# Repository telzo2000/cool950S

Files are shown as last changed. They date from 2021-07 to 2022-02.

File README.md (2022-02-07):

# cool950S
# ビルドガイド<br>
https://github.com/telzo2000/cool950S/blob/main/buildguide_for_cool950S.md

# What is cool950S?

cool950S is desined by m.ki.
<br>
cool950S is a split keyboard.
<br>
I didn't have a cool 40% keyboard, so I made one.
<br>

# 開発の経緯(Development history)<br>
cool943Sの製作した後，それに合うようなキーキャップを探したが，中々合致するものがなかった。
特にエンターキーは40%キーボードで構成されている1.75Uにしたため，ベースキット以外に，40%キットを追加購入するなど，お金がかかる事となった。
そのため，ベースキットのみで完成するキーボードがいいと思い，cool950Sの特徴の一つとした。
他に，矢印キーをレイヤーキーとの組み合わせでなく，標準で打鍵できる方が良いのかなとも考えた。
右側手前に矢印キーを置くことも特徴の一つとした。
cool943Sのバックスペースキーは2Uであった。
それを1Uサイズにすることで，スタビライザーが一つ減る。
さらにPキーの隣にひとつキーを加えられると考えた。
それらにより，右側1行目は，7つのキーとなり，左側１行目の６つのキーと合致しない。
ファームウェアの見直しが必要となる。
ROWが7になるのであれば，左側にも1つキーを加えられると考えた。
そこで，一番左側に縦方向に4つキーを加えることとした。
アルティザンキーキャップを置くことも、マクロキーを設定することもできると考えた。
バックスペースキーを1Uとすることで，左右どちらにも１行目端部にpro microの設置が可能となった。
これにより，cool943Sよりも余白の少ないデザインとすることができた。
代わりに，cool943Sよりも背の高いキーボードとなる。<br>
cool943Sはpro microを１行目キーの奥側に設置することで，背の低いキーボードに仕上げた。
私の場合は，パームレストなしで使うことができ，良い高さである。
多少の余白も手に当たることがない。
今回は１行目外端部下に設置した。
pro microを含むことで高さの制約を受けている。
トッププレート上面からボトムプレート下面までの厚みは，cool950Sが14.6mmで，cool943Sが11.6mmである。<br>
<br>
令和３年７月１７日にLEDの装着を行う。
操作の仕方がわからないが、点灯した。
配線のミスはないことが確認できた。
あとはオプション部品となるアクリル部品の設計が残っている。<br>
令和3年7月上旬に、試作1号が完成した。
アクリルのトッププレートとボトムプレートでPCBを挟むサンドイッチマウントである。
仮組みの段階で、スタビ用に開けた穴が小さいこと、その近くにあるネジとの距離が近すぎて、ネジやスペーサーに干渉することがわかった。
それにより、アクリル、PCBの両方を修正して、Ver.1.1を発注した。
ただ、スタビが使えないだけの試作1号であるが、それ以外の問題が無いか確認するため、実際に組んで、ファームウェアを入れてみた。
ファームウェアの修正は必要であったが、配線等のミスはなかった。
半田付けのミスがあり、１枚基板を廃棄した。<br>
その後、ビルド環境のラズベリーパイが不調となり、新しく構築することとなった。
新しい環境でcool950SのREMAP対応のファームウェアを作り、7月10日に完成した。
ついでに、他のキーキャップへの換装をし、ツイートした。<br>
https://twitter.com/0002ozlet/status/1413727164780843009
<br>
令和３年７月18日にオプション部品と考えていた、アクリル部品を発注した。<br>
7月24日にアクリル部品は到着して、装着した。
cool950Sはアクリル積層による密閉型ケースとなった。
当初、アクリルサンドイッチ構造と、オプションによるアクリル積層の密閉型の選択できる形を考えていた。<br>
しかし、できあがりを見て、オプションではなく、標準でアクリル積層の密閉型ケースとすることに決めた。<br>
発注した５セット分の余剰として、４セットを頒布する予定である。
スタビライザーが使えないver.1.0も訳あり品として頒布する予定である。<br>
現在、本サイトを含めて、準備をしている。
<br>
令和３年8月11日追記<br>
8月上旬にアクリル積層による密閉型ケースのcool950Sを頒布した。<br>
後日、スタビライザーが使えないver.1.0も頒布する予定。<br>

<br>
# 今後の予定（Future plans）

☑ver1.1が届いたら、一台分組み立て及び撮影<br>
☑ビルドガイドの作成<br>
☑Boothでの残りの頒布。<br>
□オプション部品の販売。<br>
<br><br>

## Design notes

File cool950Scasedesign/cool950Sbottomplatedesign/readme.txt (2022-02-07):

These are the components of the keyboard case.
The red line is the inner cutline.
The black line is the outer cutline.

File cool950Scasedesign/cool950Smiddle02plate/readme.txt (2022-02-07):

These are the components of the keyboard case.
The black line is the cutline.

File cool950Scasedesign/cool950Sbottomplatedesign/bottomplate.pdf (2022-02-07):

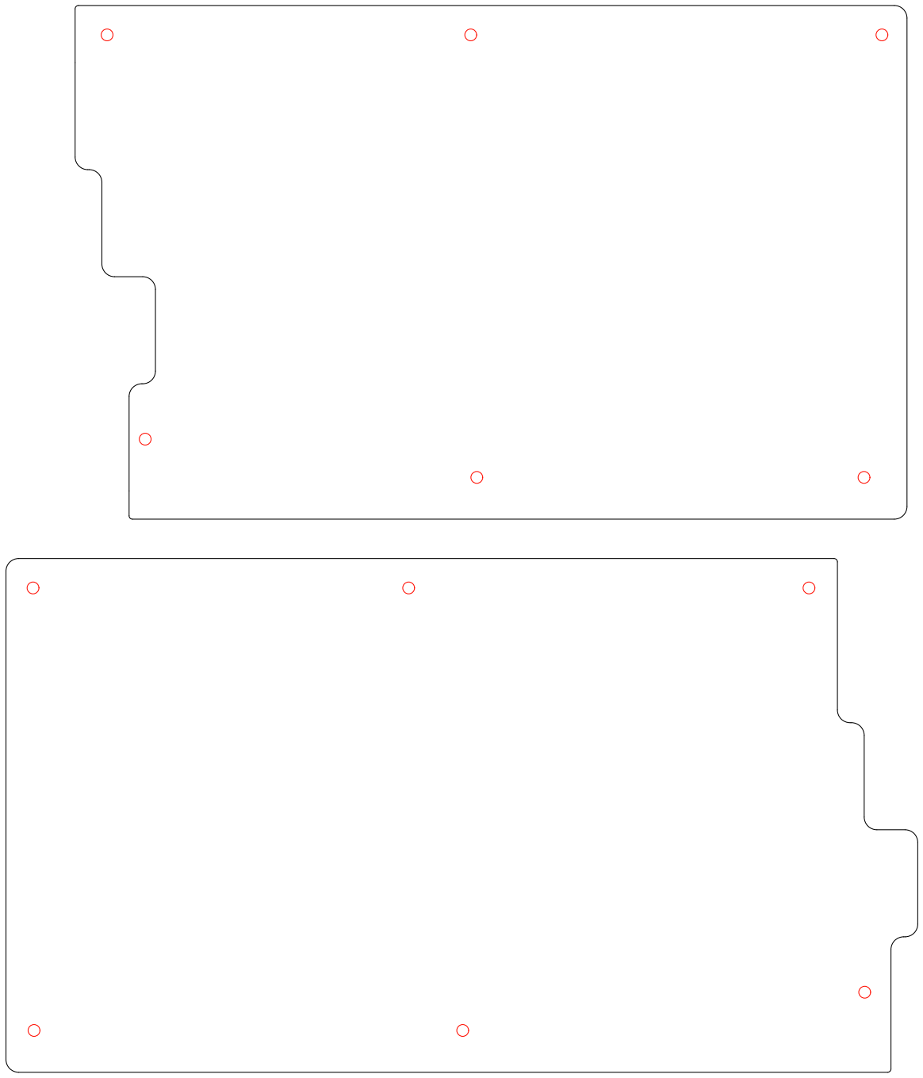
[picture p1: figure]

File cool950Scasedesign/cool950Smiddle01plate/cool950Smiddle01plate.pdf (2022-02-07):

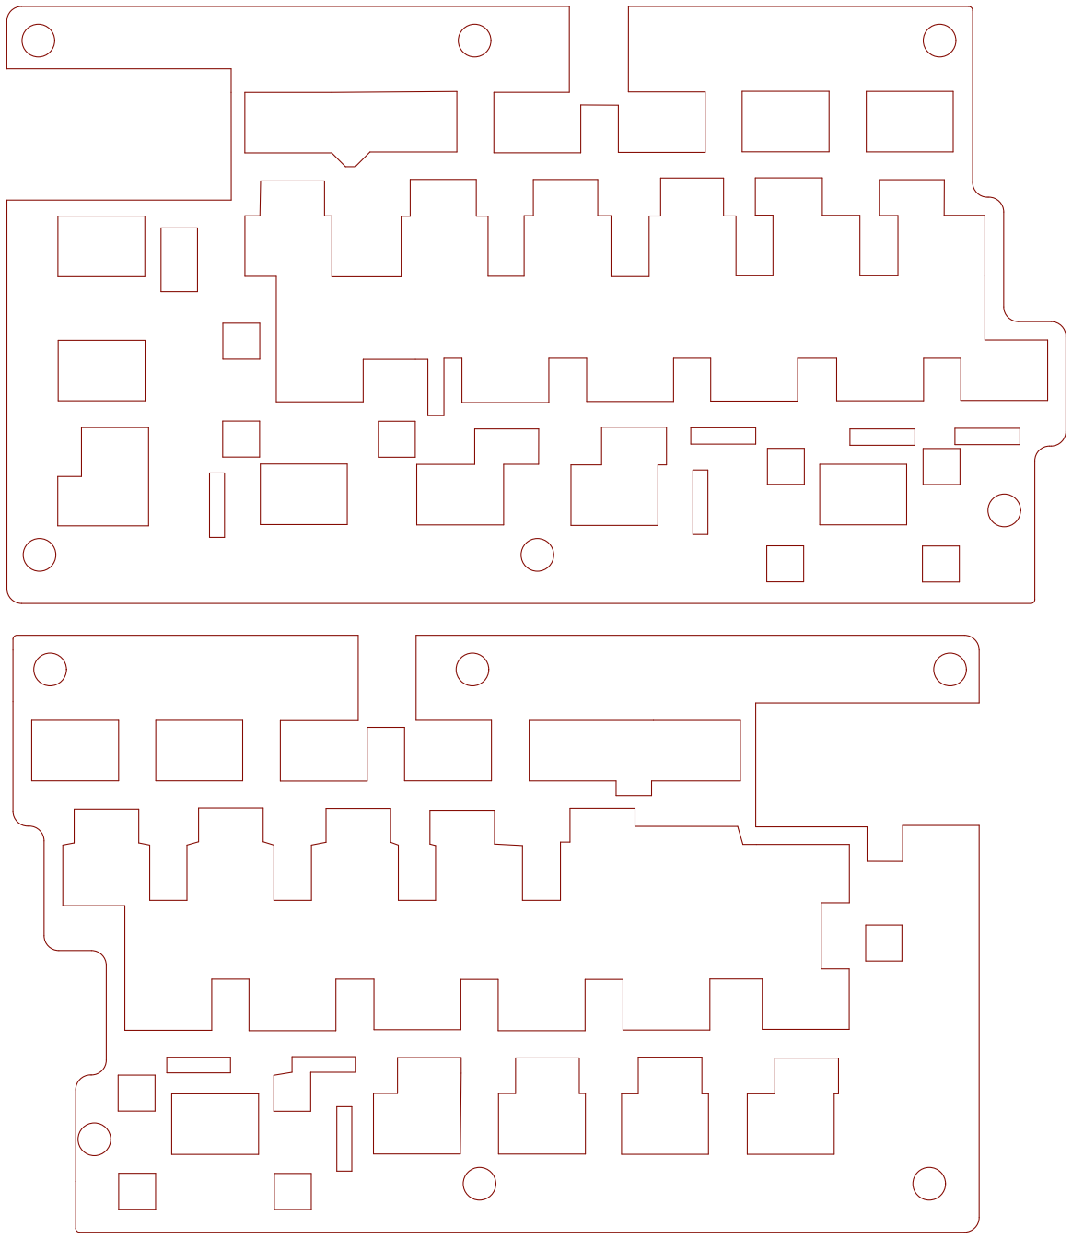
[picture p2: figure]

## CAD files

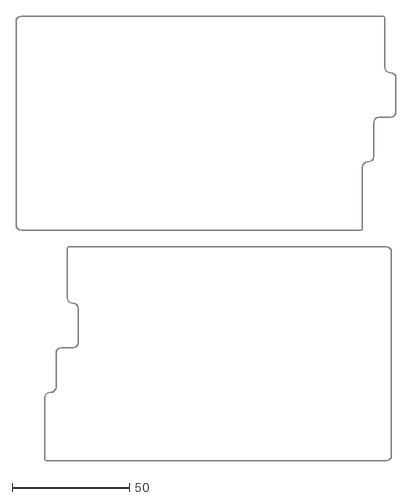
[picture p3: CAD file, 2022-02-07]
cool950Scasedesign/cool950Sbottomplatedesign/bottomplate.dxf
162.2 x 189.8

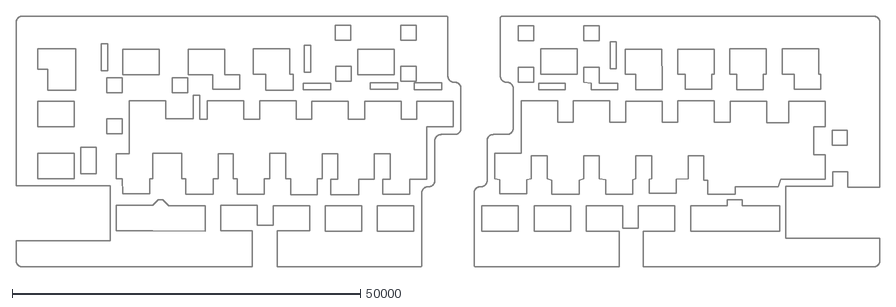
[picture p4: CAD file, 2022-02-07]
cool950Scasedesign/cool950Smiddle01plate/cool950Smiddle01plate.dxf
123985.3 x 35990.0

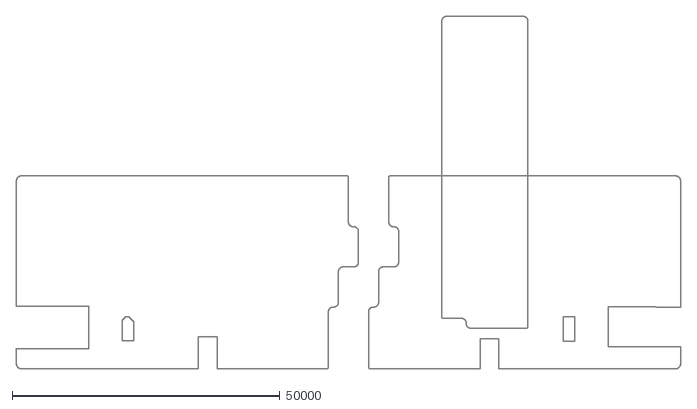
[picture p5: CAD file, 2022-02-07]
cool950Scasedesign/cool950Smiddle02plate/cool950Smiddle02plate.dxf
123985.0 x 65789.0

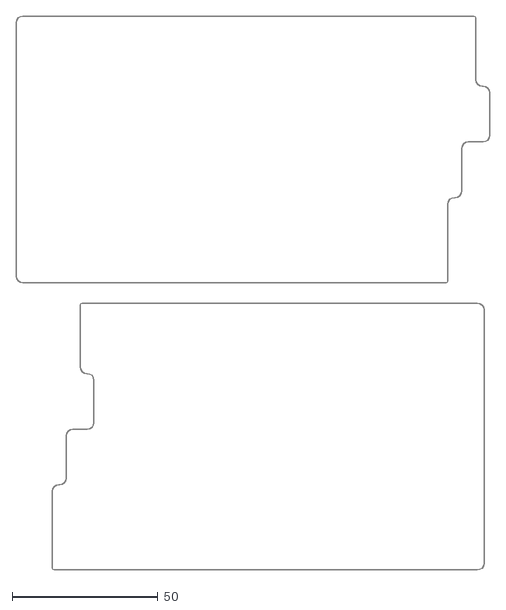
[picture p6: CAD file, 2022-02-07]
cool950Scasedesign/cool950Stopplatedesign/topplate.dxf
162.2 x 189.8

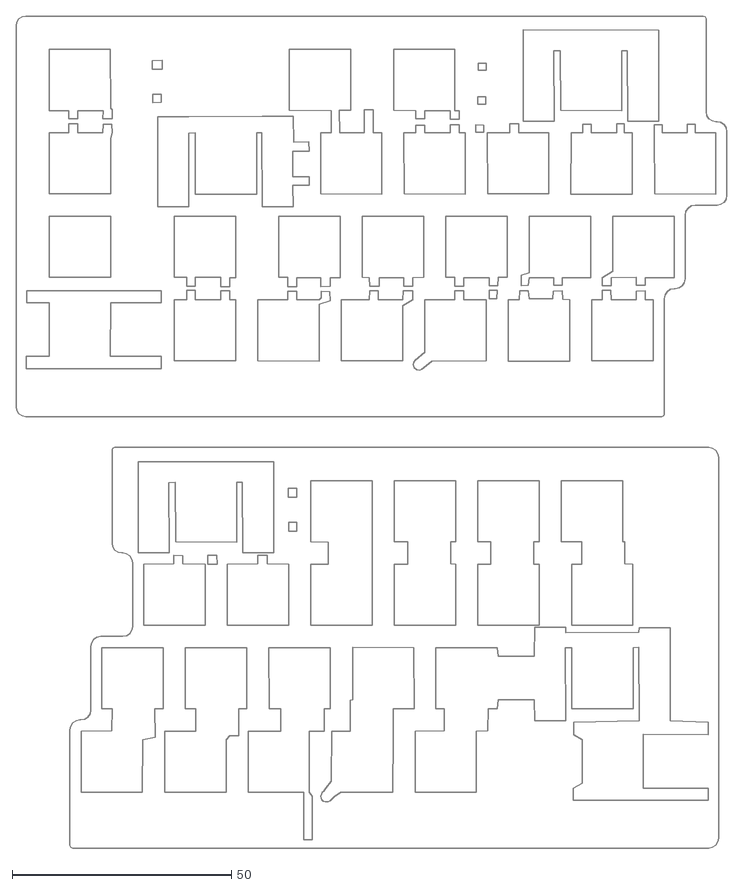
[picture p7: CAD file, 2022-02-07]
cool950Scasedesign/cool950Stopplateunderdesign/topplateunder.dxf
162.2 x 189.8

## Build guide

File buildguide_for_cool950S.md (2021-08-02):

# cool950S　ビルドガイド
## 特徴
<br>
cool950Sは、m.kiが設計した40％分割キーボードです。<br>
入力に必要なキー以外を省略することでコンパクトにしました。<br>
トッププレートからアクリルを積層することで密閉型ケースに仕上げました。<br>
<br>

## 1　部品の確認
次の部品で構成されています。<br>
１　　PCB　左右それぞれ１枚<br>
２　　トッププレート　左右それぞれ１枚<br>
３　　トップアンダープレート　左右それぞれ１枚<br>
４　　ミドルプレート１　左右それぞれ４枚<br>
５　　ミドルプレート２　左右それぞれ１枚<br>
６　　ボトムプレート　左右それぞれ２枚<br>
７　　M２ネジ（４mm12本、８mm12本）<br>
８　　M２スペーサー３mm六角形タイプ６個、６mm六角形タイプ６個<br>
９　　Pro micro　２個<br>
１０　TRRSジャック　２個<br>
１１　タクトスイッチ　２個<br>
１２　TRRSケーブル １本<br>
１３　ダイオード　50個<br>
１４　LEDテープ　２枚<br>
１５　スタビライザー（２Uサイズ）　４個<br>
１６　キースイッチ　50個<br>
１７　キーキャップセット　※任意<br>
１８　USBケーブル（Pro microの端子に準拠したもの）<br>
１９　ゴム足（ウレタンクッション）　８つ<br>
<br>
部品のうち、<br>
１〜８、１０〜１３、１５はキットに同封されています。<br>
９、１４、１６〜１９は遊舎工房、TALP KEYBOARDS、KOCHI KEYBOARDで店頭もしくはネット通販で購入可能です。<br>
９のpro microについては、マック８コンスルー（スプリングピンヘッダ）が必要となります。<br>
<br>

## ２　ファームウェアについて
cool950Sはyouichiro氏の開発したREMAPにて、キーレイアウトの編集ができます。<br>
次の[Hexファイル](https://github.com/telzo2000/cool950S/blob/main/cool950S_via.hex)をダウンロードしてください。そして、QMK TOOLBOXにてPro microへの書き込みをしてください。<br>
REMAPで作業するための[Jsonファイル](https://github.com/telzo2000/cool950S/blob/main/cool950S_remap.json)はこちらにあります。<br>
chromeを起動して、「REMAP」と検索し、REMAPのサイトへアクセスしてください。<br>
cool950Sとパソコンをケーブルでつなぎ、REMAPのサイトへアクセスすると、
cool950Sのキーレイアウトが変更できます。<br>
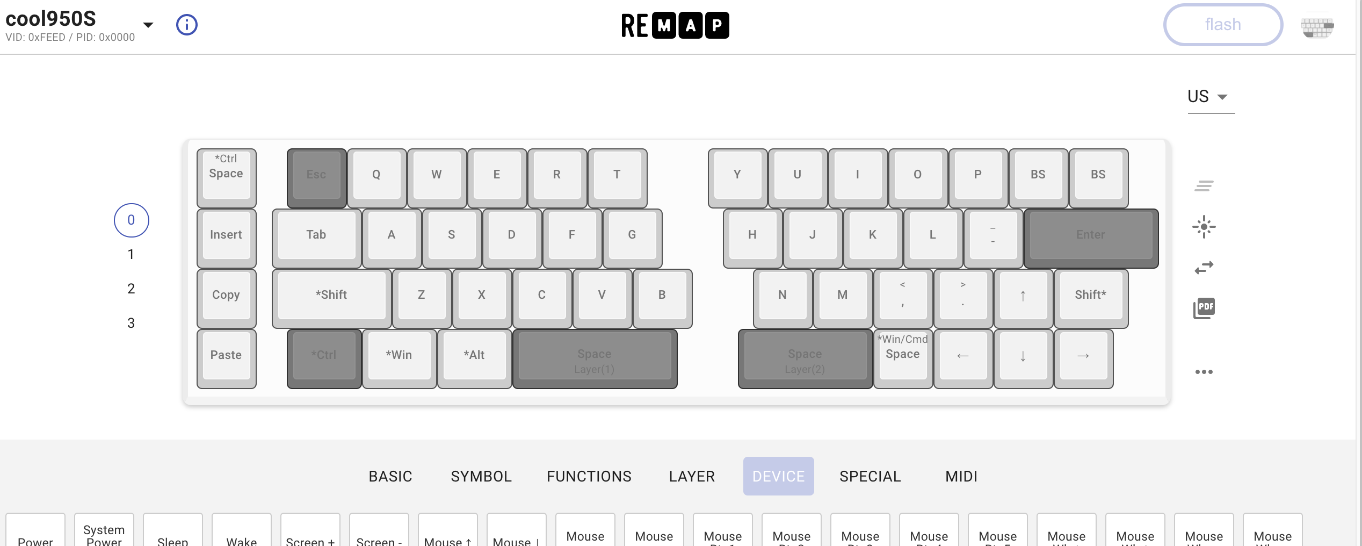
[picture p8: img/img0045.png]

## ３　色塗り
PCBの側面を黒色マジックで塗ってください。
cool950Sはトッププレートが黒色アクリルプレートを使用していますので、
PCBの側面も同じ黒色のほうが格好良くなります。<br>
<br>

## ４　ダイオードのハンダ付け
ダイオードの足を曲げて取り付けて、ハンダ付けをします。<br>
ダイオードの足は、下面から「diode」と印刷された部分の穴に差し込みます。
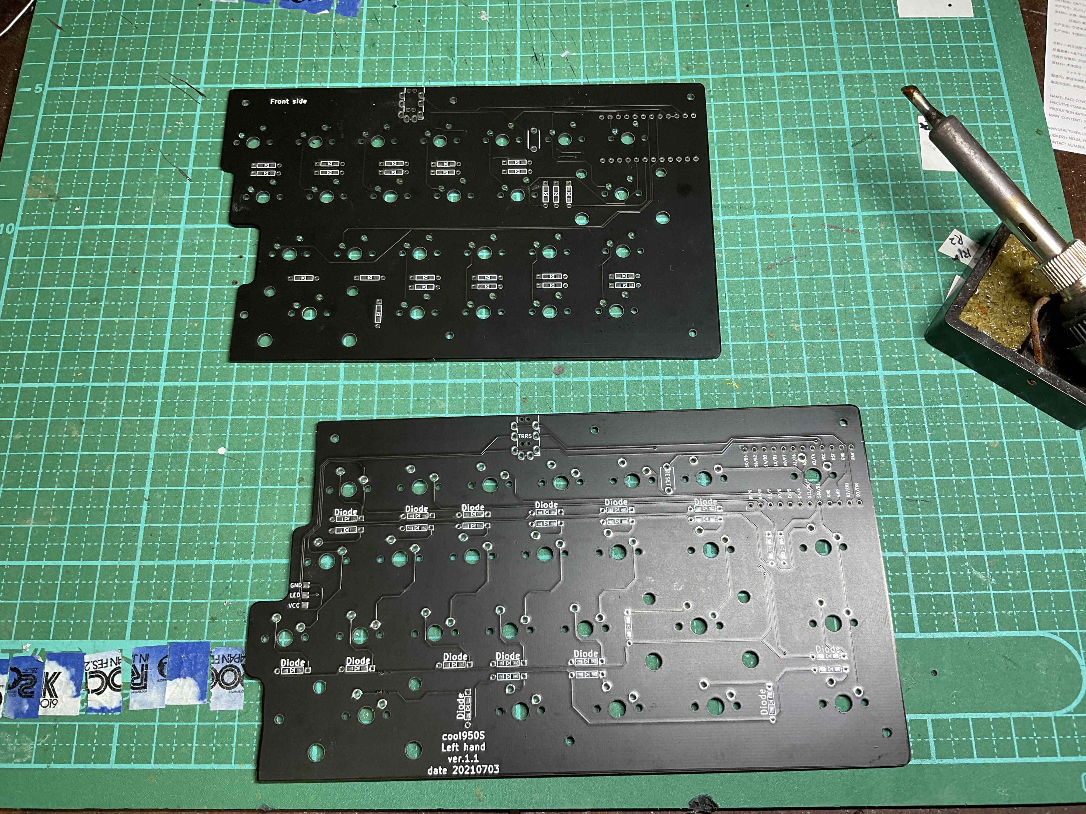
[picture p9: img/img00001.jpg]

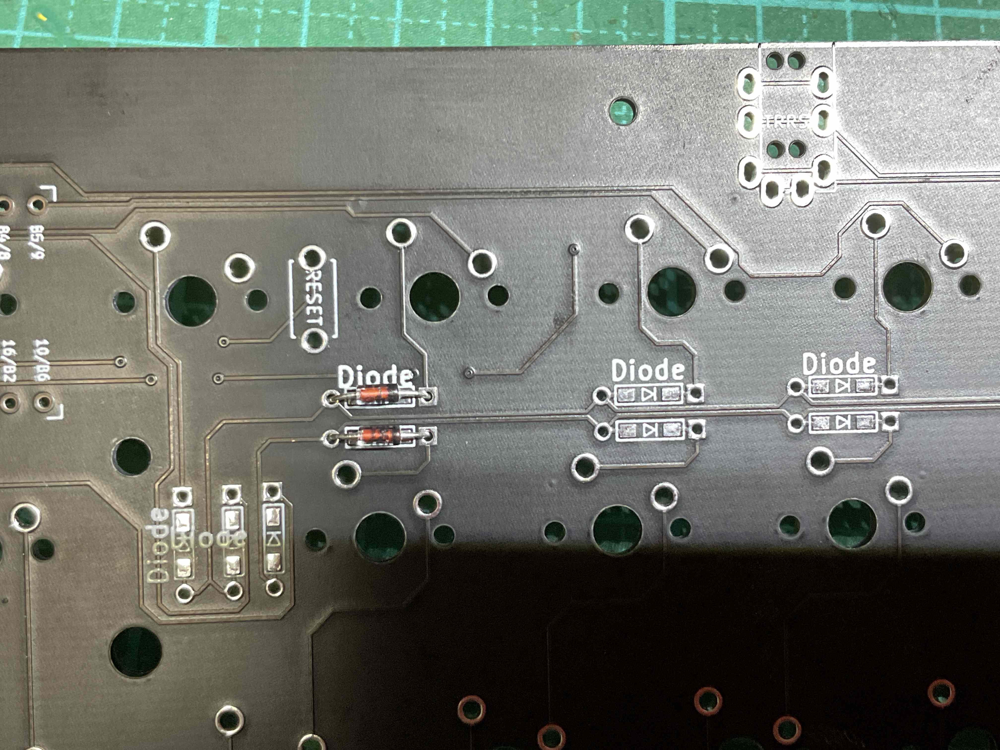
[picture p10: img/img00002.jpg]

短く切ったマスキングテープで固定してから、裏返して、上面に伸びたダイオードの足は切り離してください。
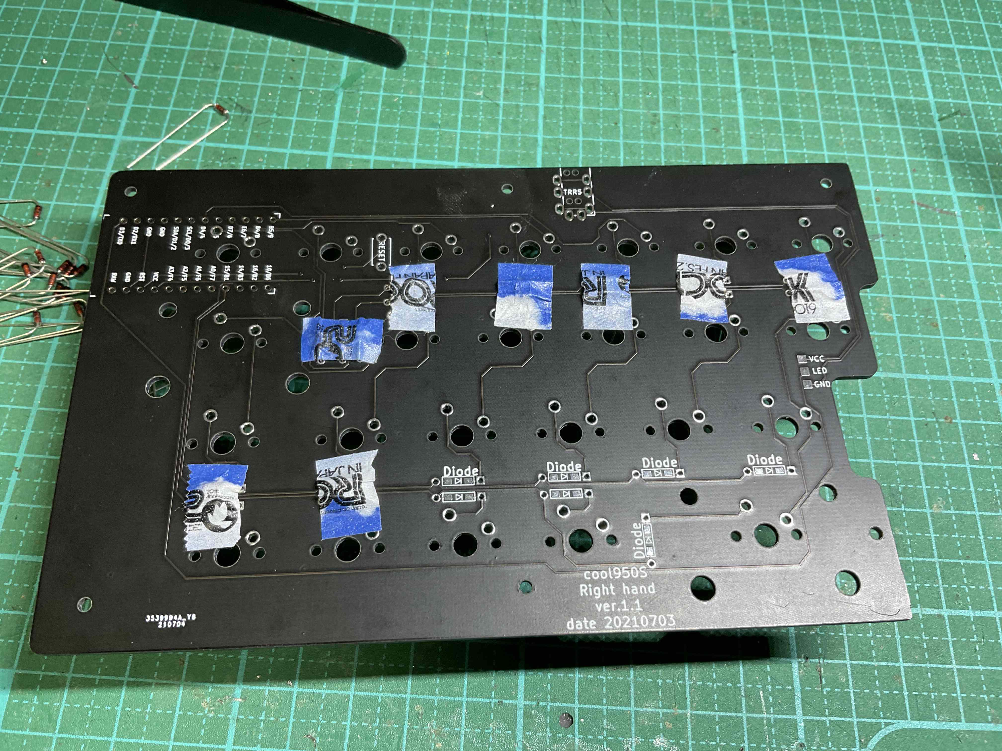
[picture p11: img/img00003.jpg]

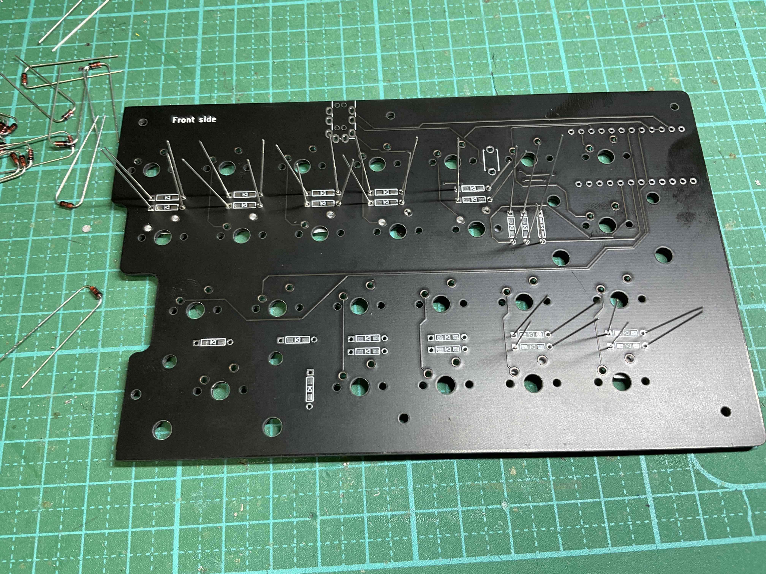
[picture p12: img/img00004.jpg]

ダイオードには極性があります。ダイオードの黒い帯がある側が「diode」の文字の後ろになるようにハンダ付けしてください。
もし、文字の印刷がない場所は、他のダイオードの向きを確認して、同じようにハンダ付けをしてください。<br>
ハンダ付けに自信がない場合、フラックスを利用すると、上手にハンダ付けができます。<br>
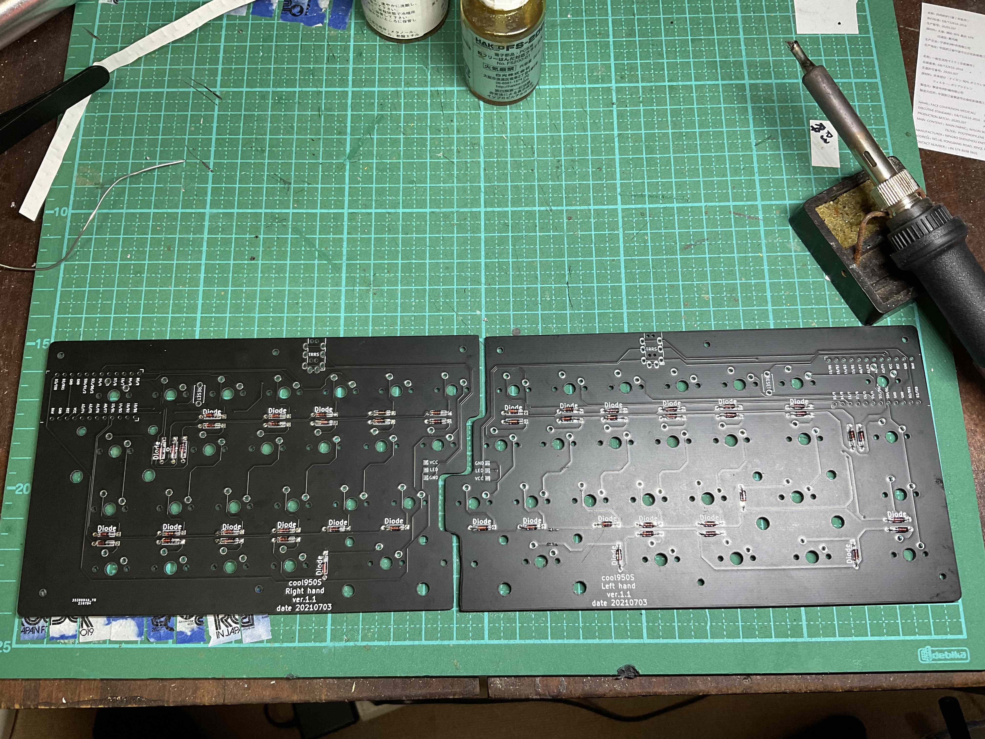
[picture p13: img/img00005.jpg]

その後、フラックスクリーナーで綺麗に拭き取ることをお勧めします。<br>
https://twitter.com/0002ozlet/status/1418881247648964608

## 5　タクトスイッチのハンダ付け
左右それぞれのPCBにタクトスイッチをハンダ付けします。<br>
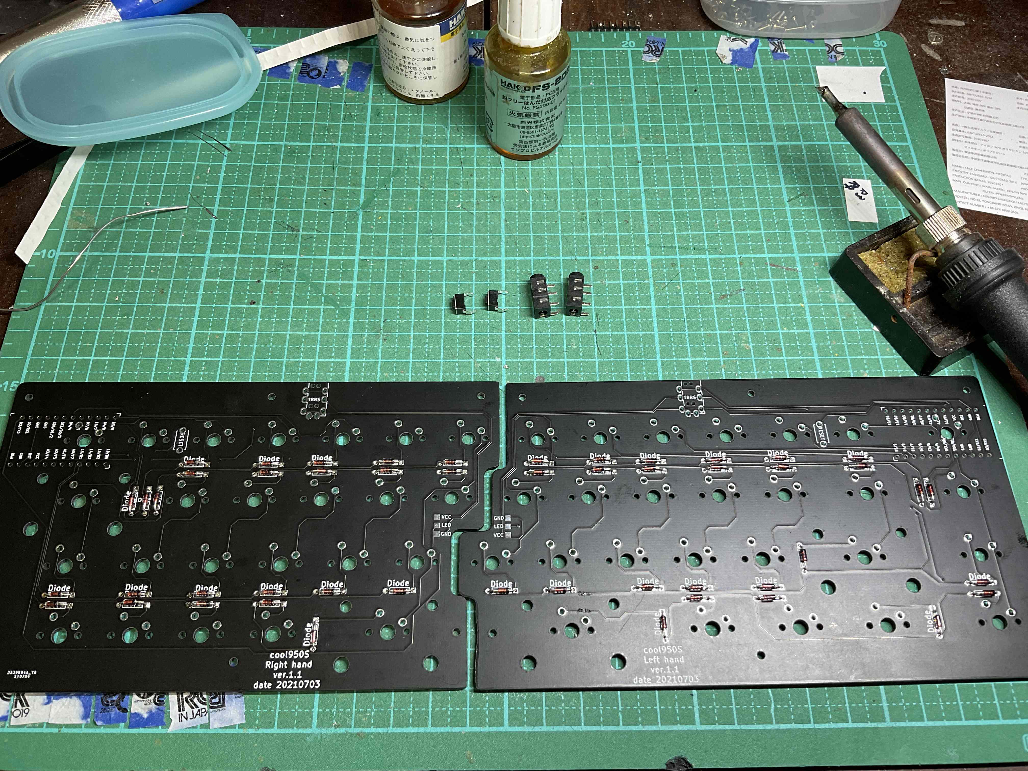
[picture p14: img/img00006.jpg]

PCBに「reset」の文字が印刷されています。
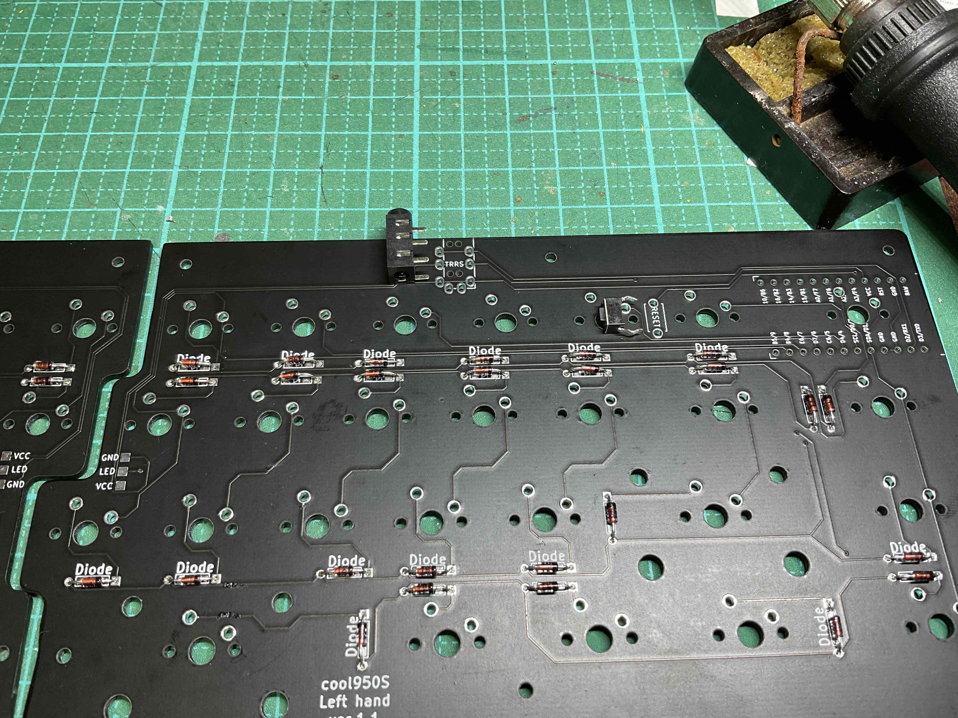
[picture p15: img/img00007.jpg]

文字が隠れるようにタクトスイッチを置いて、その裏側からハンダ付けをします。<br>
https://twitter.com/0002ozlet/status/1418884394085879808
<br>
※ツイートで言うリセットスイッチとは、このタクトスイッチのことです。

## ６　TRRSジャックのハンダ付け
左右それぞれのPCBにTRRSジャックのハンダ付けをします。<br>
ダイオードやタクトスイッチを同じ側にTRRSジャックを取り付けます。<br>
https://twitter.com/0002ozlet/status/1418896366999248897

## ７　スタビライザーの装着
４つのスタビライザーを装着します。左右のPCBの上側に２つずつ、装着します。<br>
装着する前に、スタビライザーにはルブをすることを推奨します。
ルブについては、様々な手法がありますので、ご自身で調べて実施してください。<br>
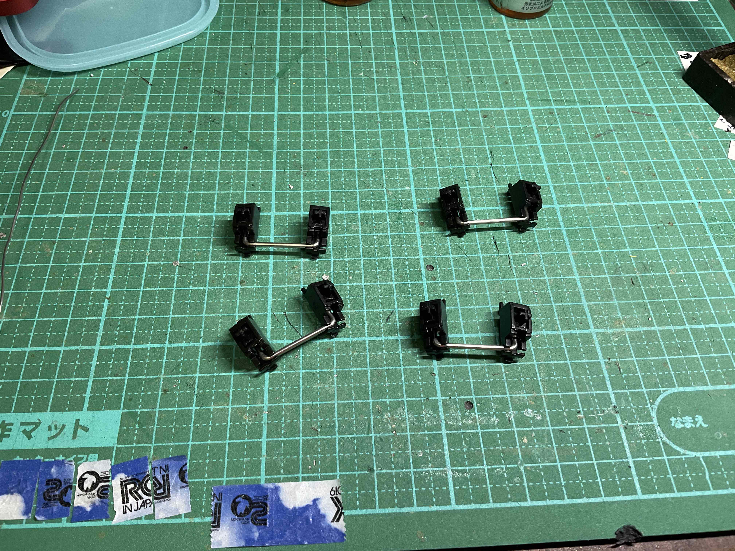
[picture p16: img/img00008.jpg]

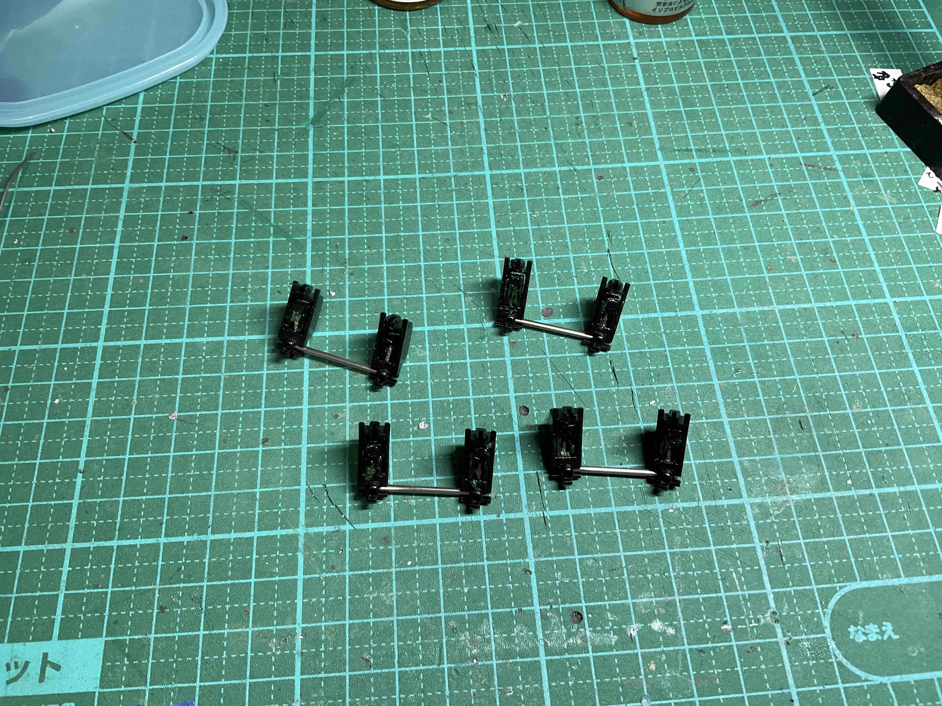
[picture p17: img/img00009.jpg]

スタビライザーについては、一度装着しますと、cool950Sでは後日交換することが困難です。<br>
同封のスタビライザーは爪のある方を先に大きめの穴に引っ掛けてから、反対側を小さめの穴にはめ込みます。<br>
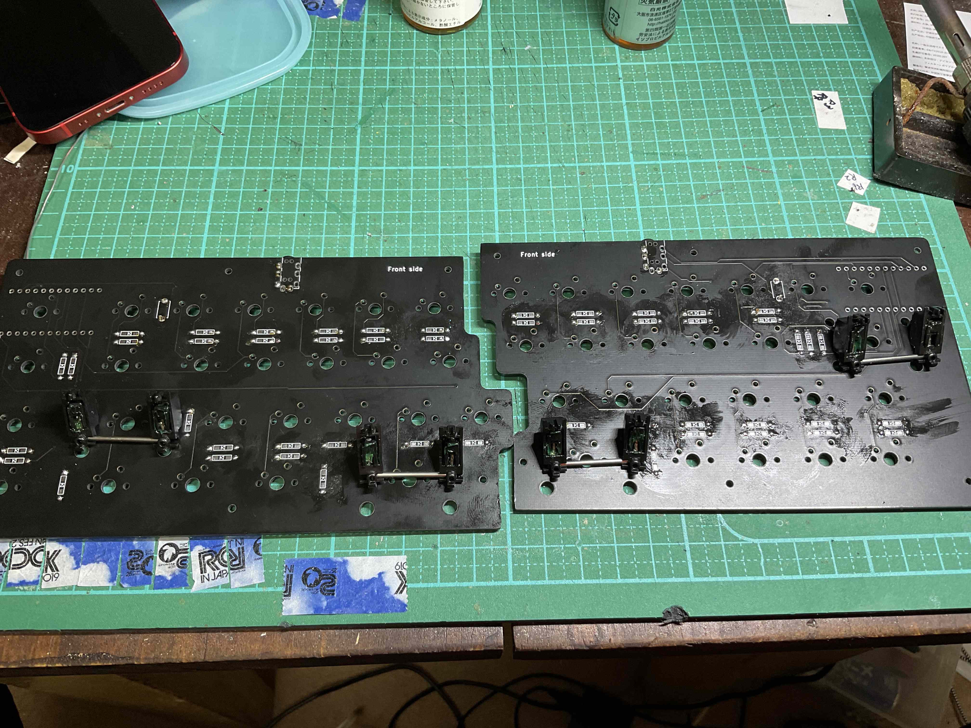
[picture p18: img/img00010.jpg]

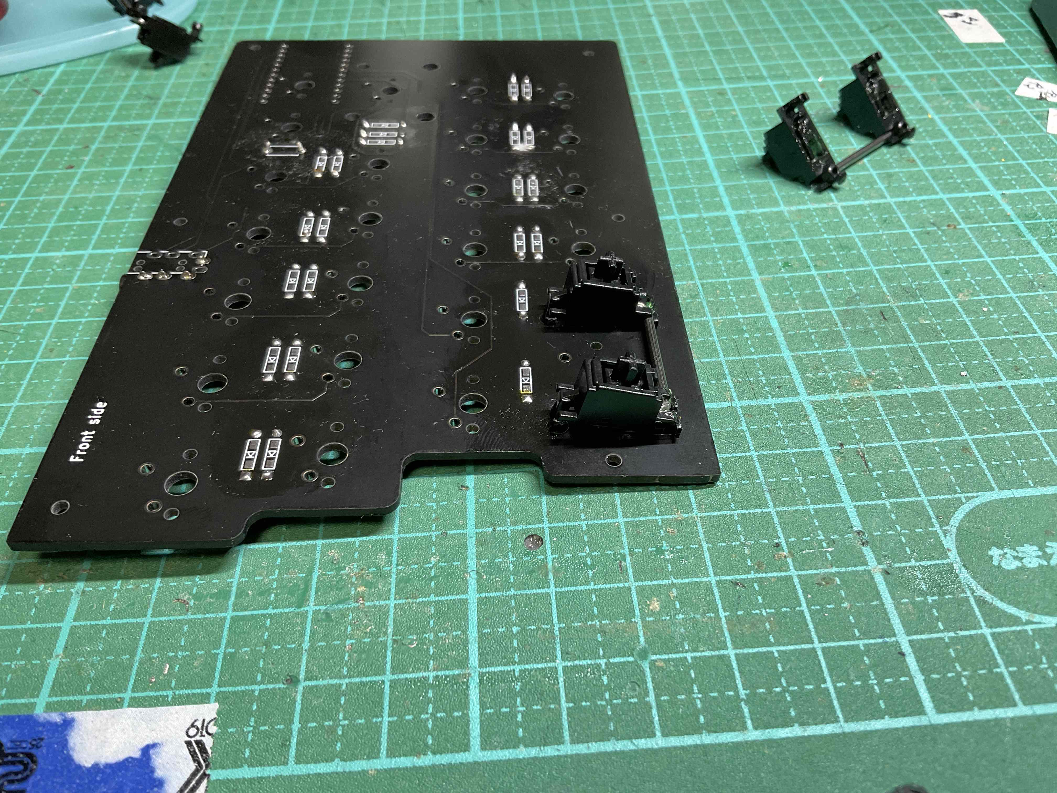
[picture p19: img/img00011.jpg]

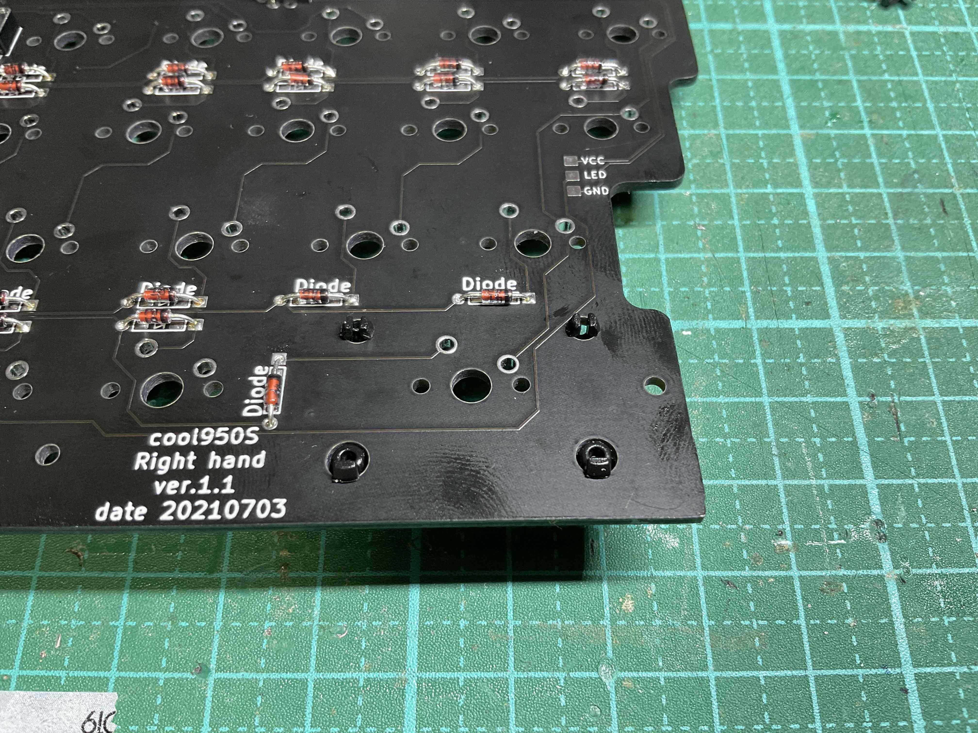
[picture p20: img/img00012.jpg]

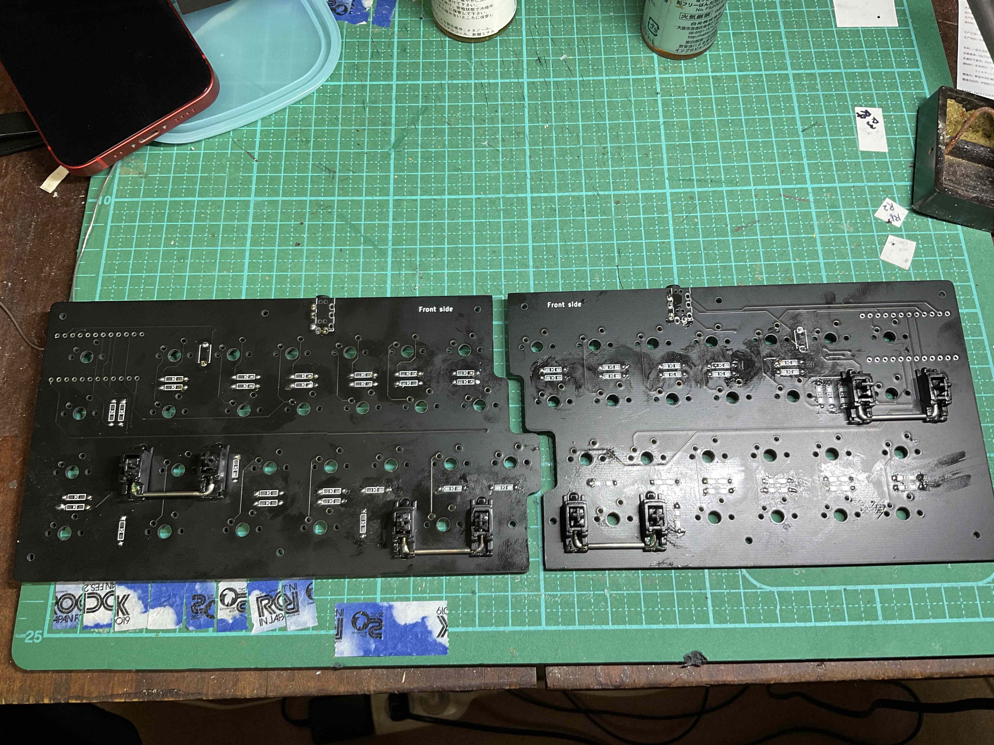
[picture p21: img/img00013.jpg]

同封されているスタビライザーより、よいものもあります。
ご自身で調べて、付け替える等の判断をしてください。<br>
https://twitter.com/0002ozlet/status/1418897654382276611

## ８ トッププレートとトップアンダープレートの装着
左右それぞれのPCBの上（PCB上に「Front side」と表示）に、トッププレート、トップアンダープレートを上から順に重ねます。<br>
アクリルの保護紙を剥がす時は、ゆっくり丁寧に行ってください。<br>
力強く乱暴に剥がしますと、保護紙の粘着に引っ張られる形で、アクリルが破損する可能性があります。<br>
焦らず、丁寧が基本です。<br>
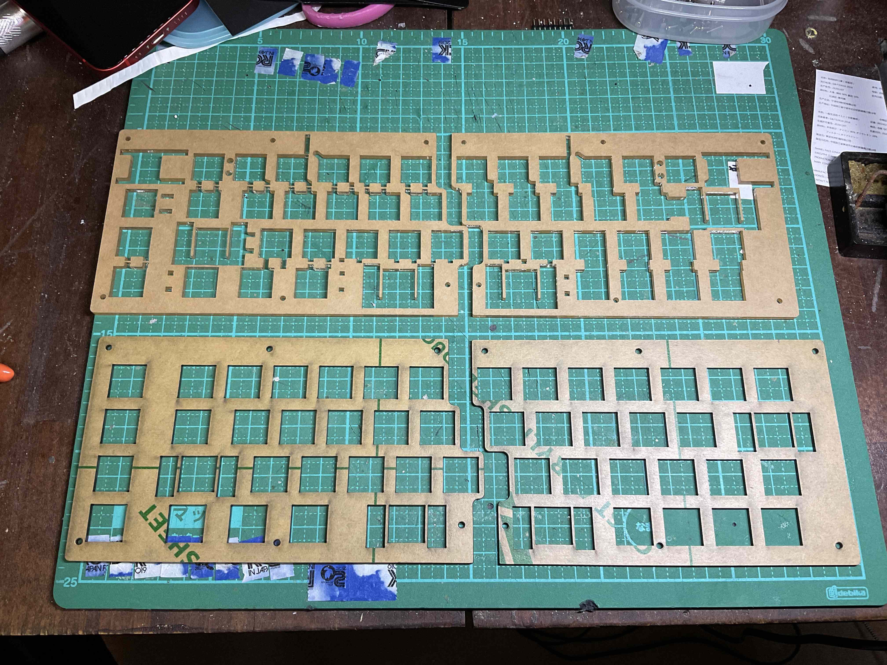
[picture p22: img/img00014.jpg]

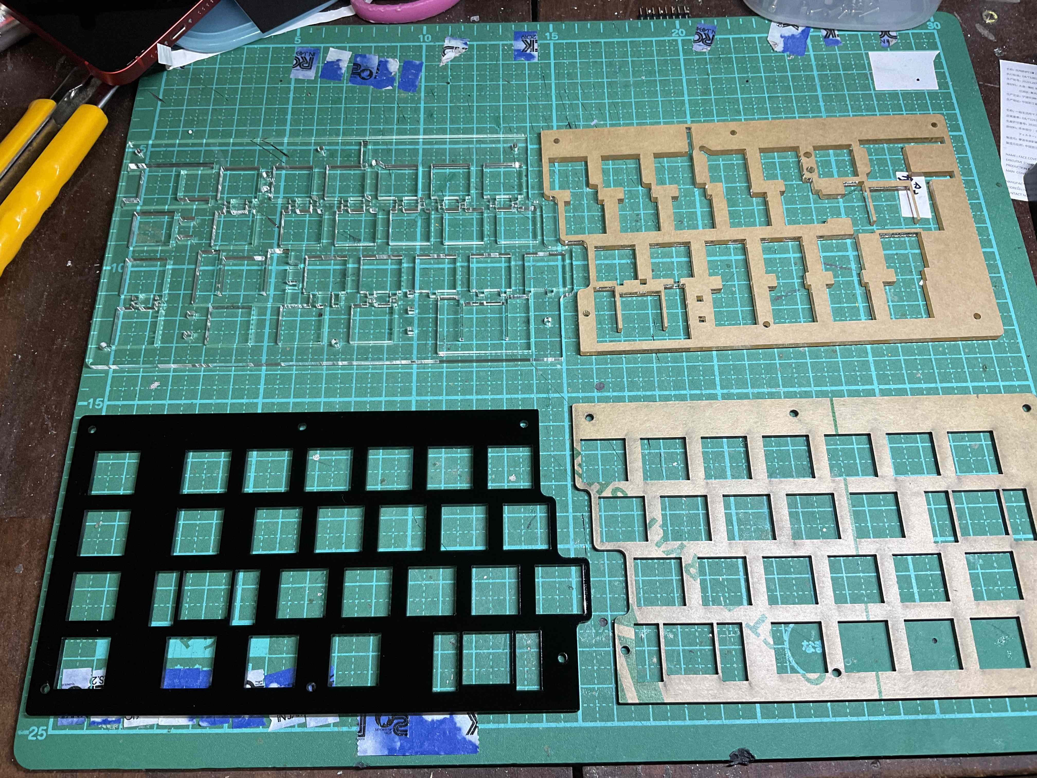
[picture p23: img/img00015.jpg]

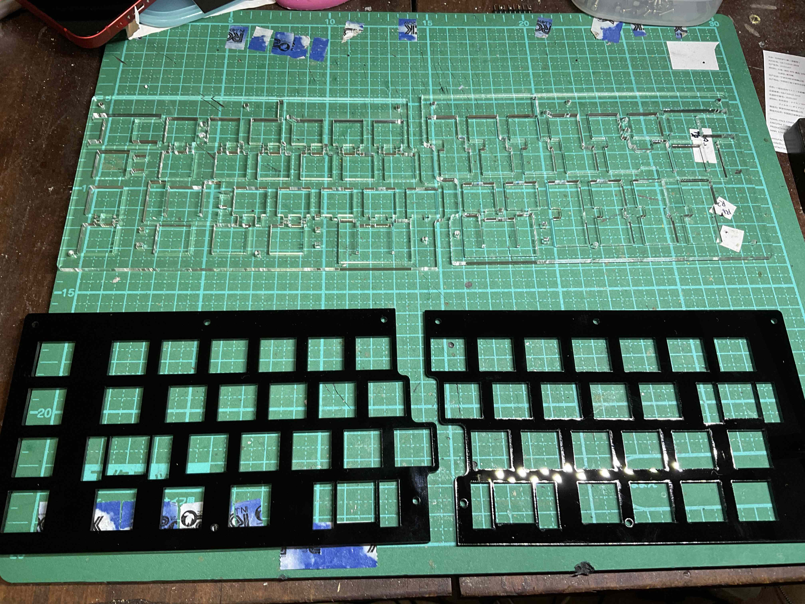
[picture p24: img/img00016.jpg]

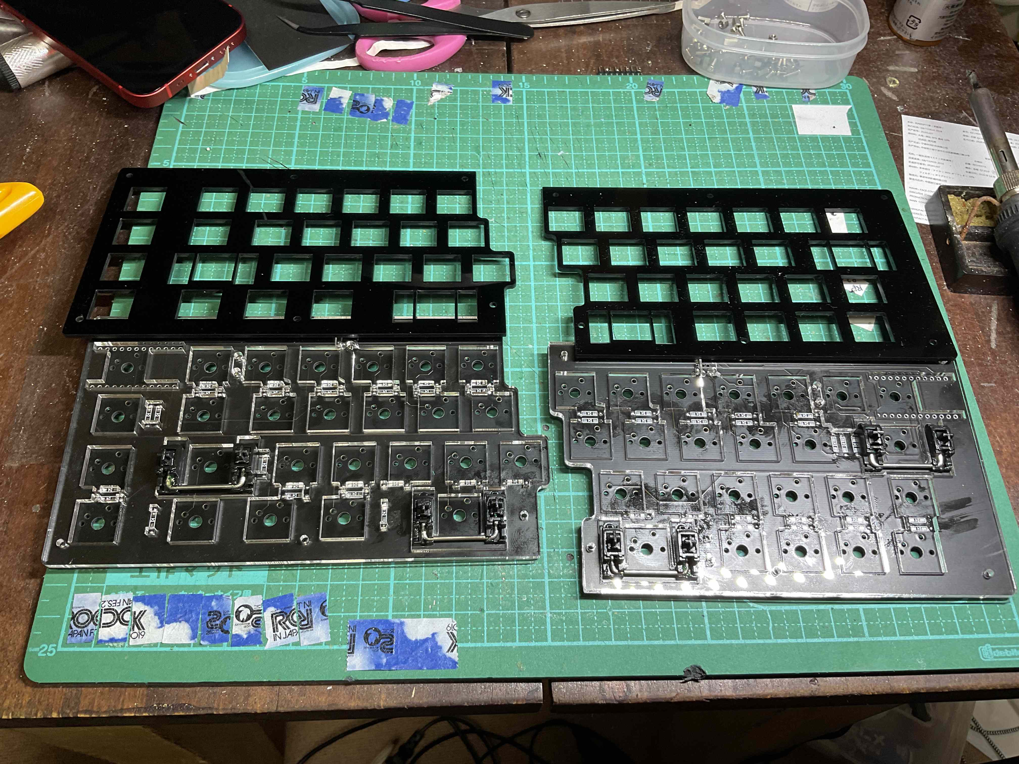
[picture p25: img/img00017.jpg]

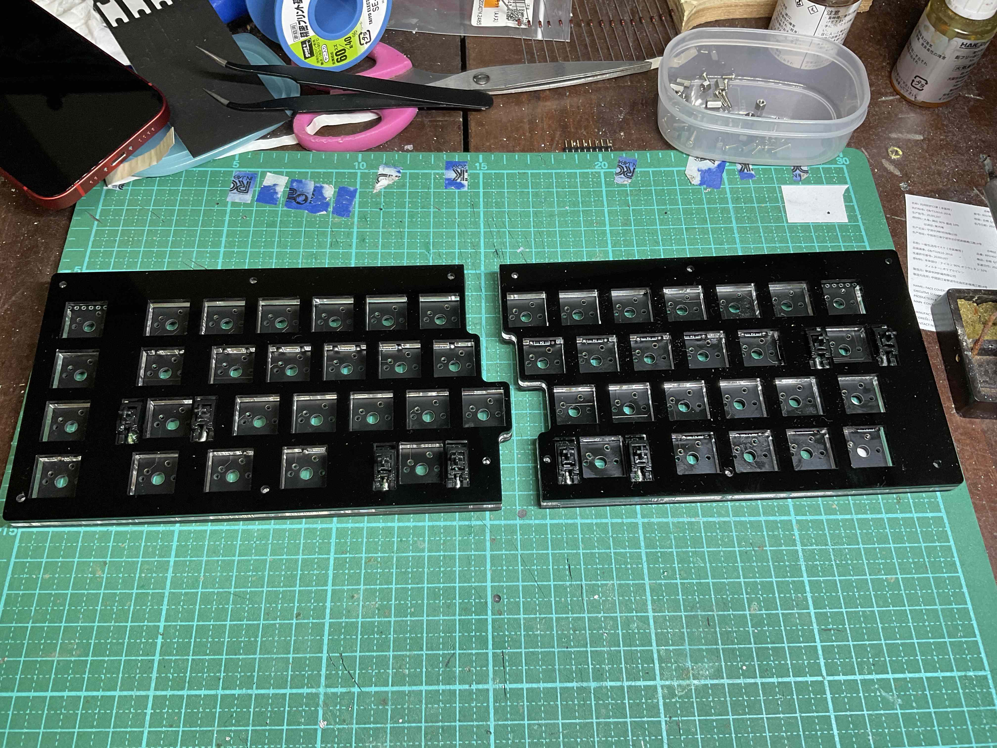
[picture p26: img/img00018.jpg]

ネジ穴の位置を意識して、表裏、左右の向きを間違えないように重ねてください。<br>
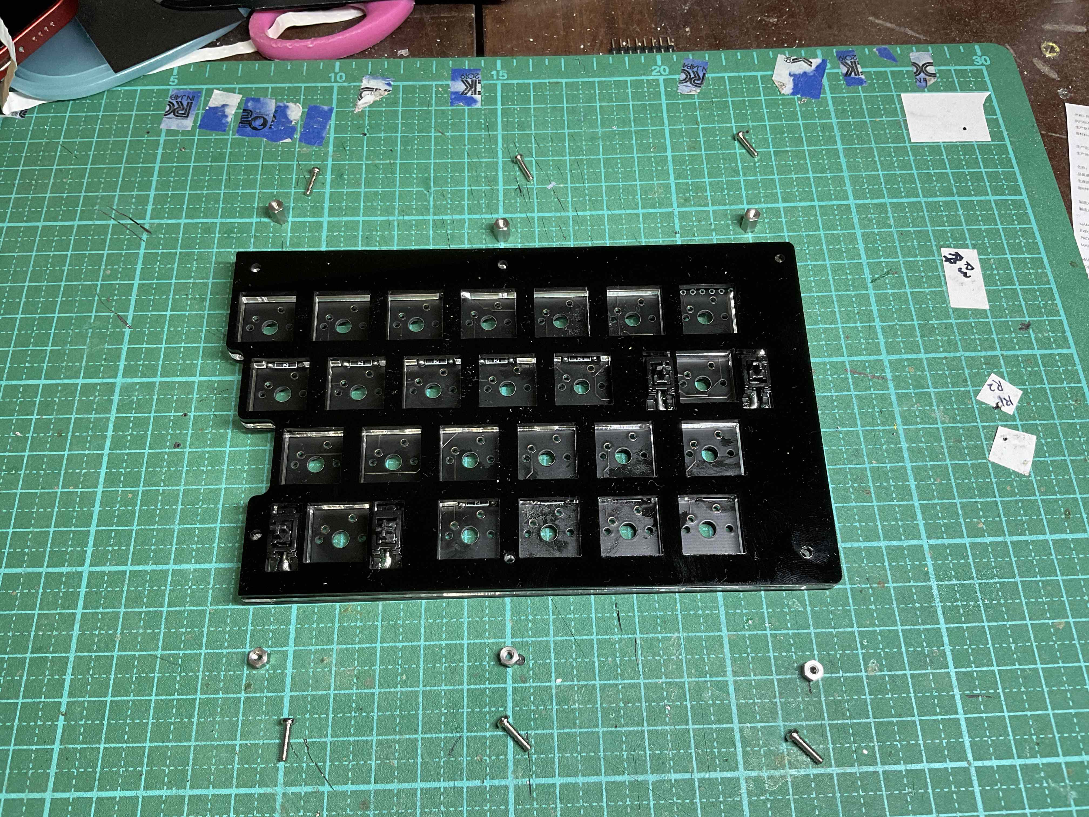
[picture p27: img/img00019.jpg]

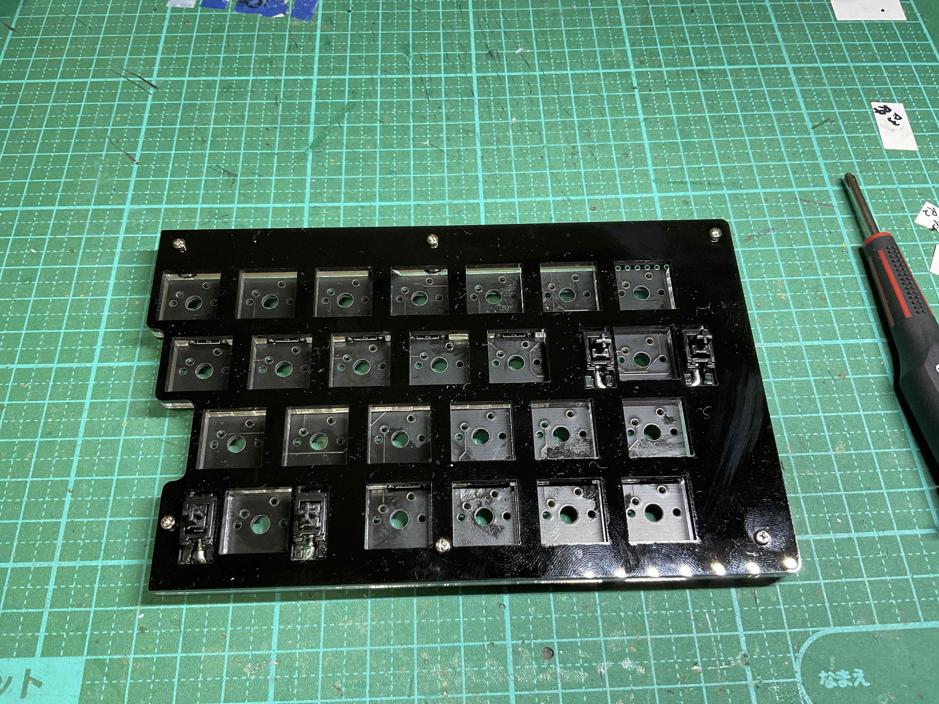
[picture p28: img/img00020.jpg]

重ねたら、ネジ穴に、M2ネジ8mmを上から通して、PCBの下側からM2スペーサー3mm及びM2スペーサー6mmで固定します。<br>
cool950Sでは、高さの違う２種類のスペーサーを使います。
原則、手前側にM2スペーサー3mm、奥側にM2スペーサー6mmを使います。<br>
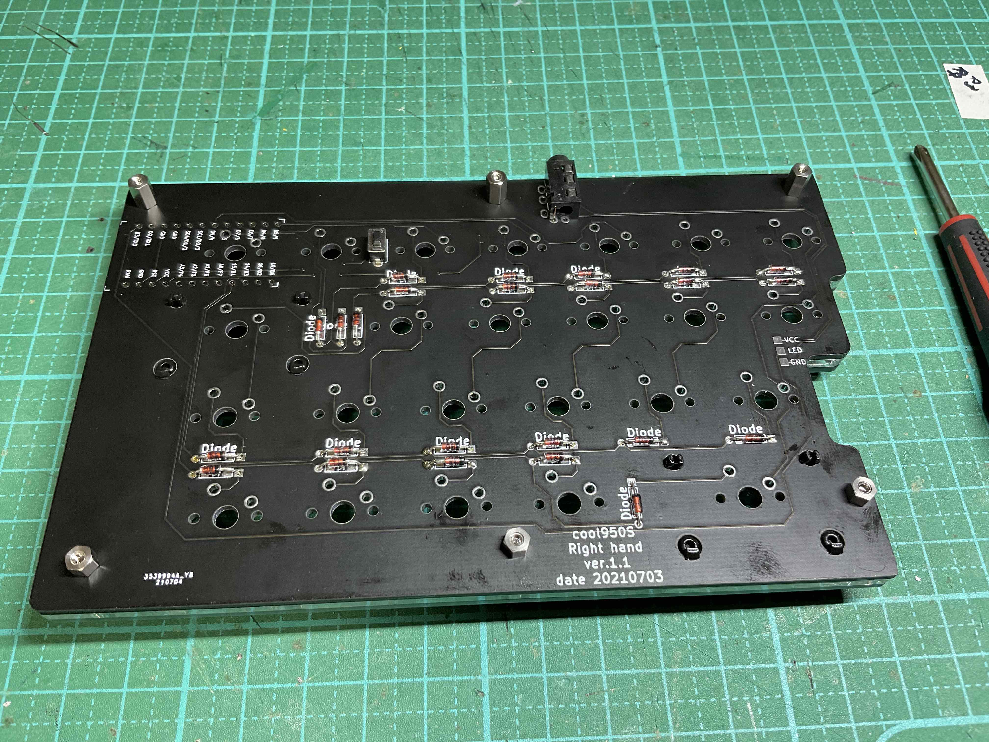
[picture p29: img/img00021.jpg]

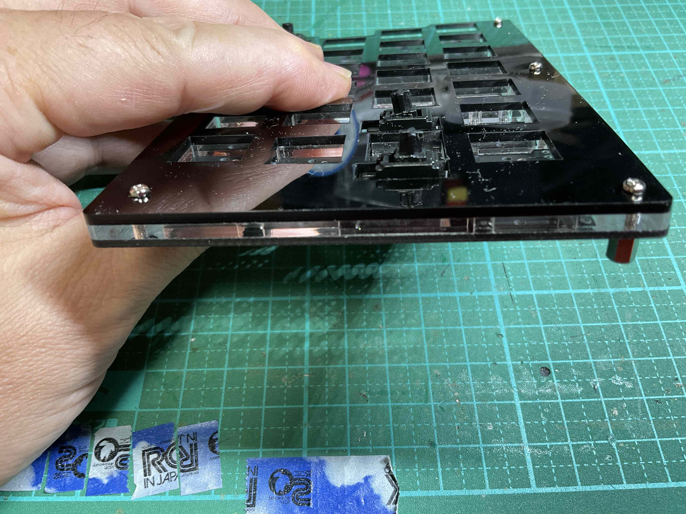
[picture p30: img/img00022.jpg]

ただし、アクリルの精度の問題から、M2スペーサー6mmではやや頭が出てしまうことがあります。<br>
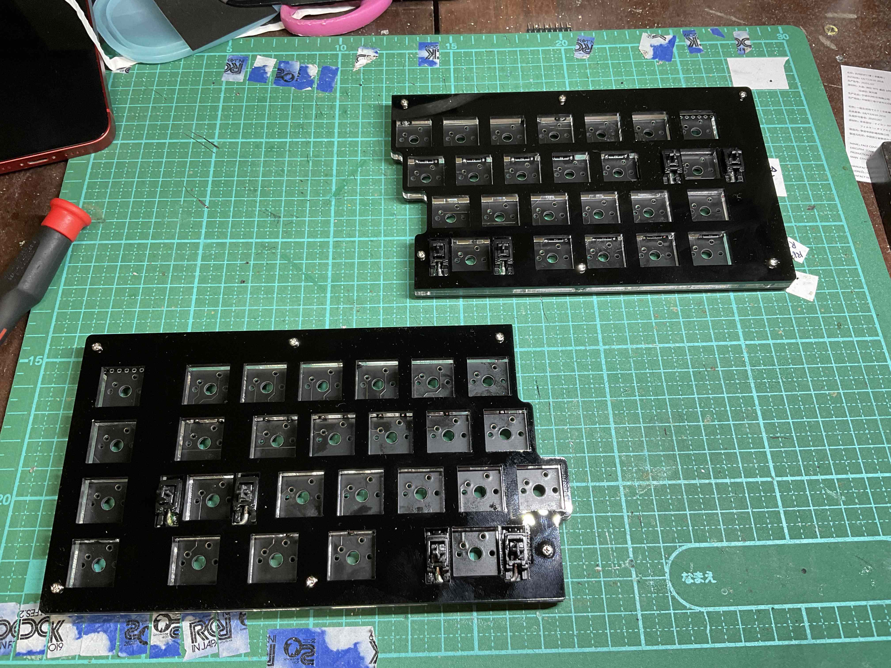
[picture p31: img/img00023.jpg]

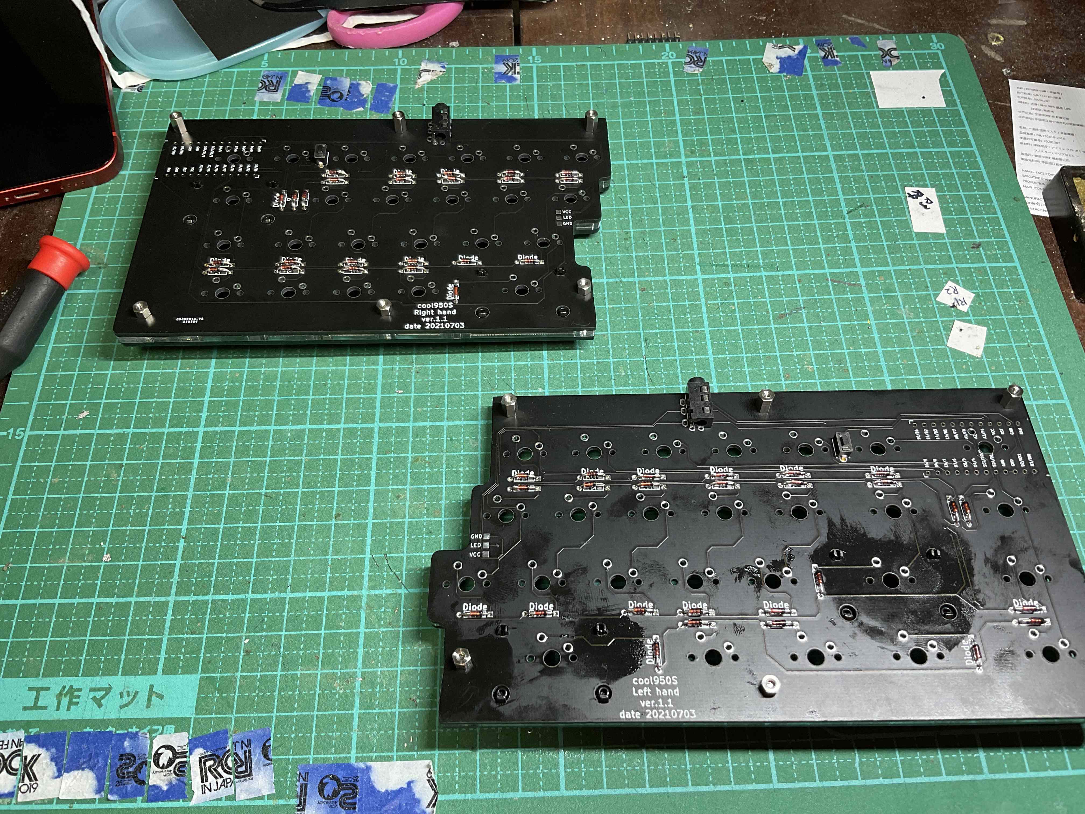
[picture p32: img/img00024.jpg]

奥側の中央と内側の２箇所（左右で４箇所）はM2スペーサー5mmを使うと、後述のミドルプレート１・２、ボトムプレートが隙間なく重なると思います。<br>
https://twitter.com/0002ozlet/status/1418898629901815812

## ９　キースイッチのハンダ付け
トッププレート側から、キースッチを装着して、ハンダ付けをします。<br>
キースイッチを強く差し込みます。差し込んだ時PCBの下側に、キースイッチの端子が少し、はみ出ます。
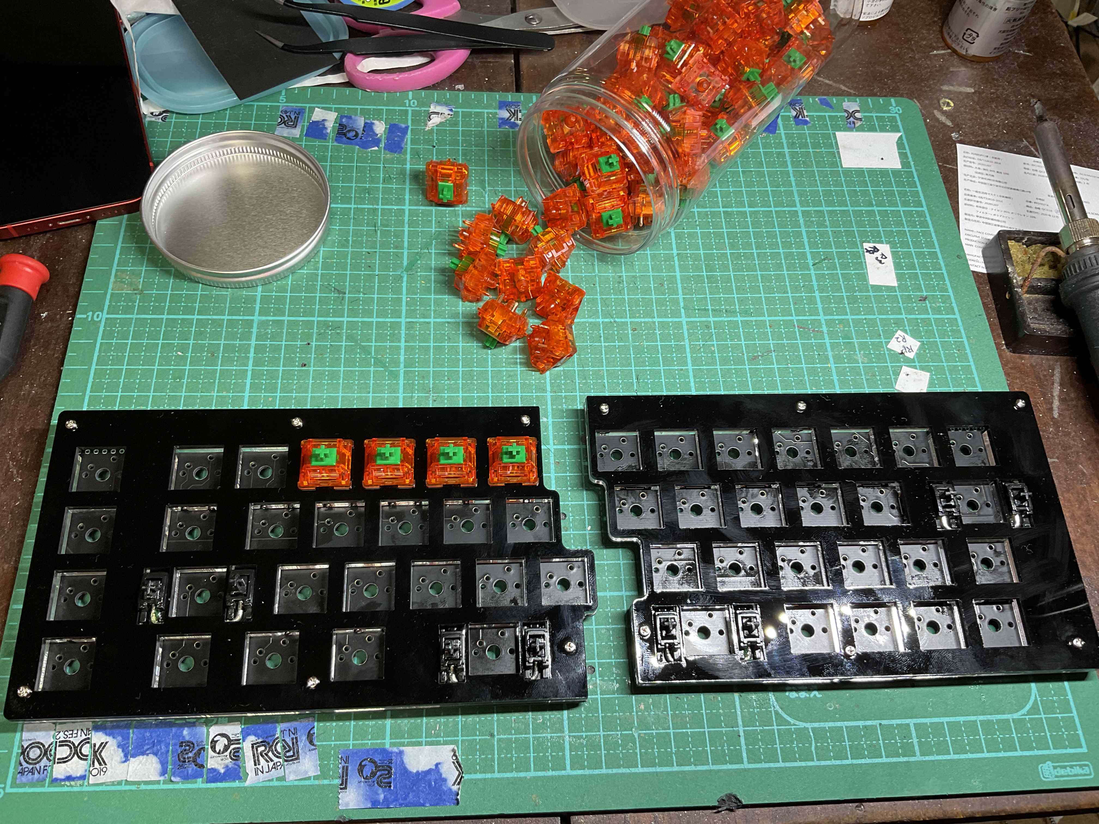
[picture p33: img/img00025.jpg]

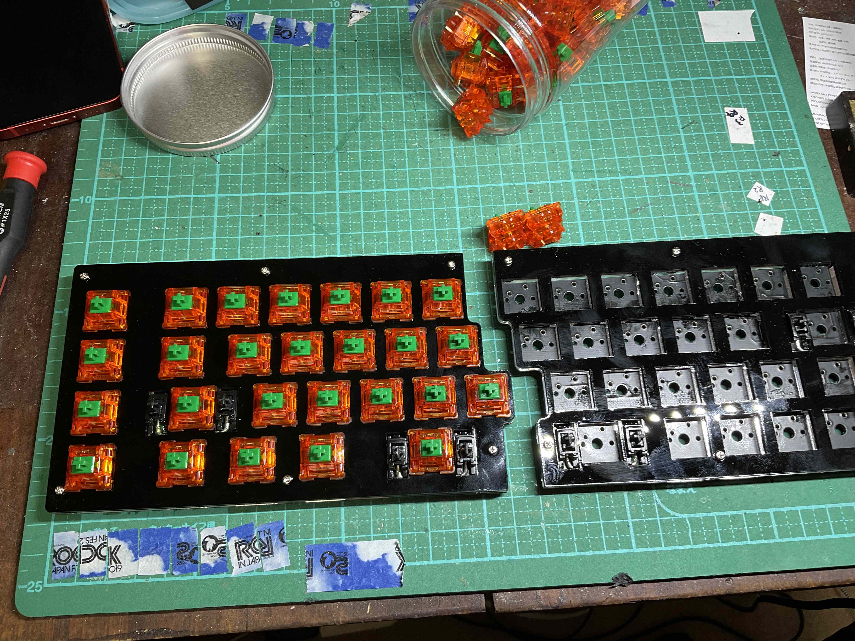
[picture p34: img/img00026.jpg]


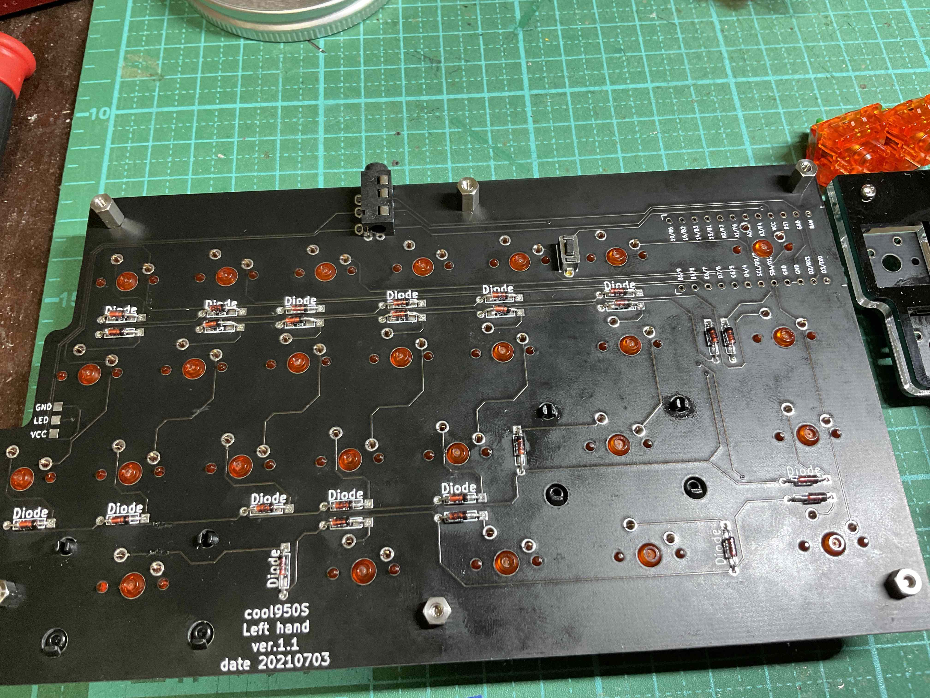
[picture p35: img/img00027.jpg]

もし、はみ出ていない時は、端子が曲がったまま、差し込まれています。
一度、キースイッチを外して、曲がった端子を修正して、差し込み直してください。<br>
キースイッチを差し込み終えたら、PCBの下側から、キースイッチの端子にハンダ付けをします。<br>

pro microを被さるように設置する箇所のキースイッチでは、
ショート防止のため、キースイッチの端子の先をニッパーでカットします。<br>
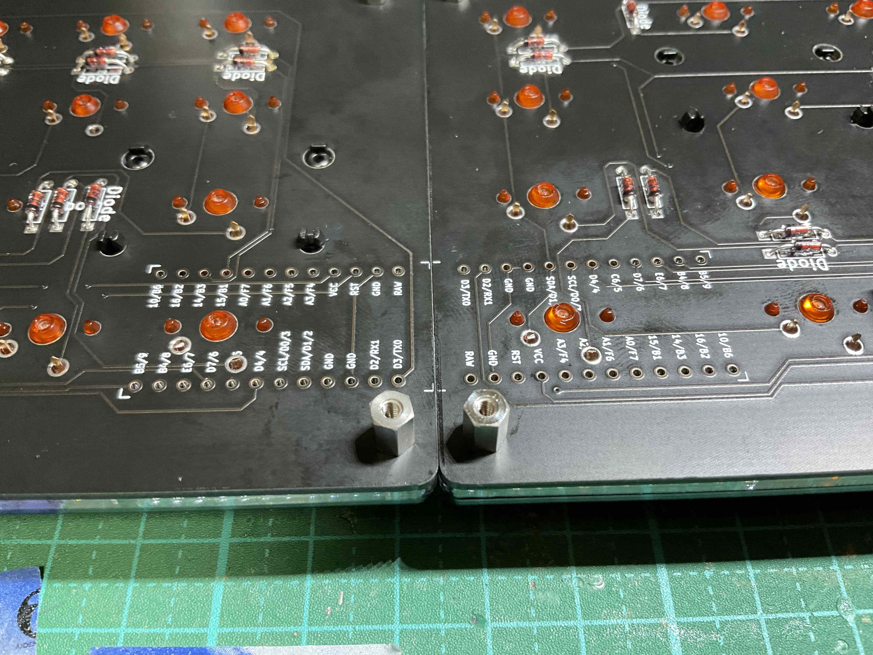
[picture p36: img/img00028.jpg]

ここまでくると、ゴールは近いです。<br>
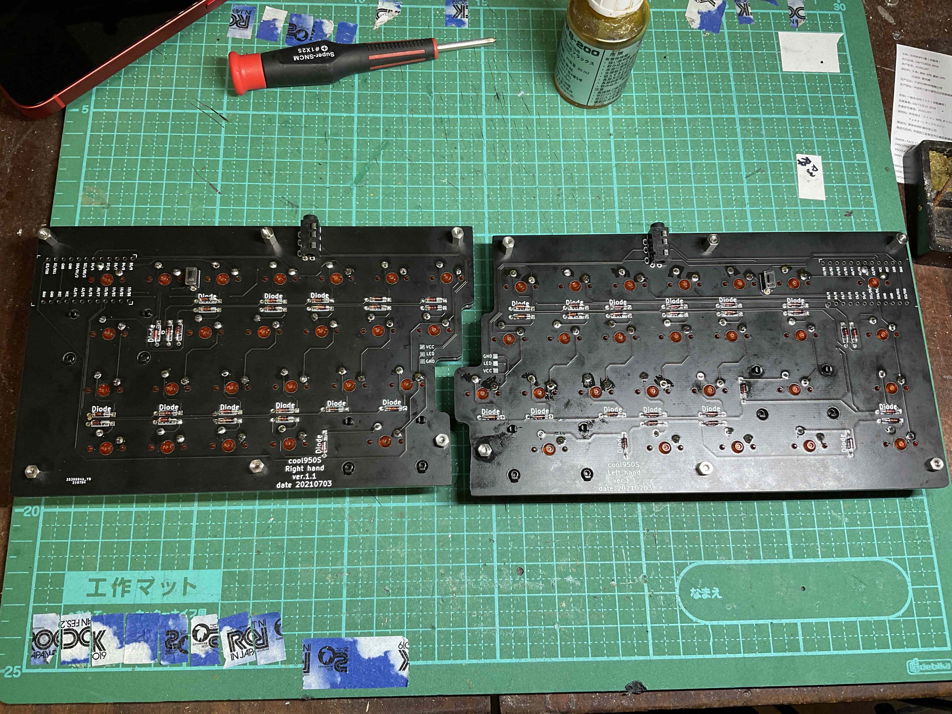
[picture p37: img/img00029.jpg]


## １０　LEDテープのハンダ付け（任意）
別途購入したLEDテープがあれば、PCBにハンダ付けをします。<br>
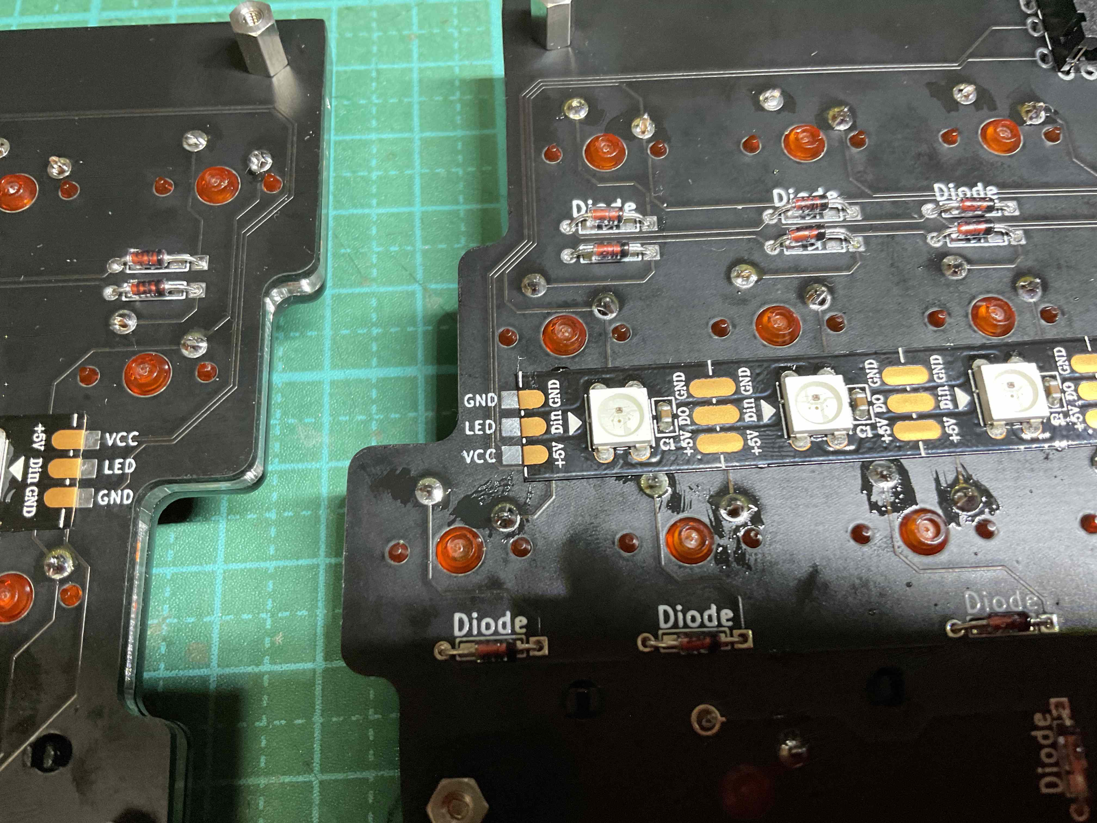
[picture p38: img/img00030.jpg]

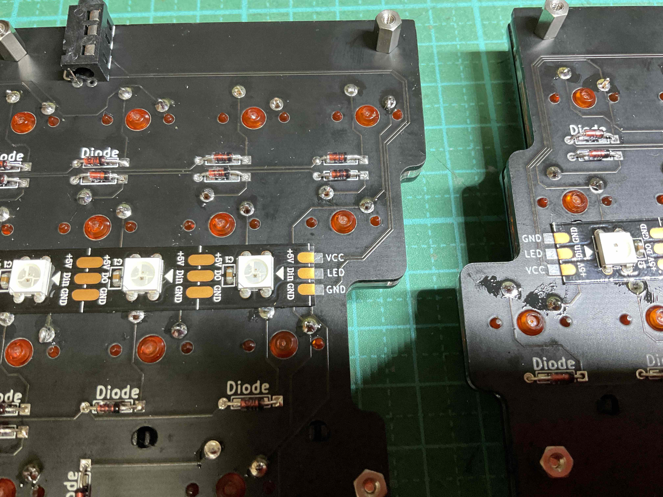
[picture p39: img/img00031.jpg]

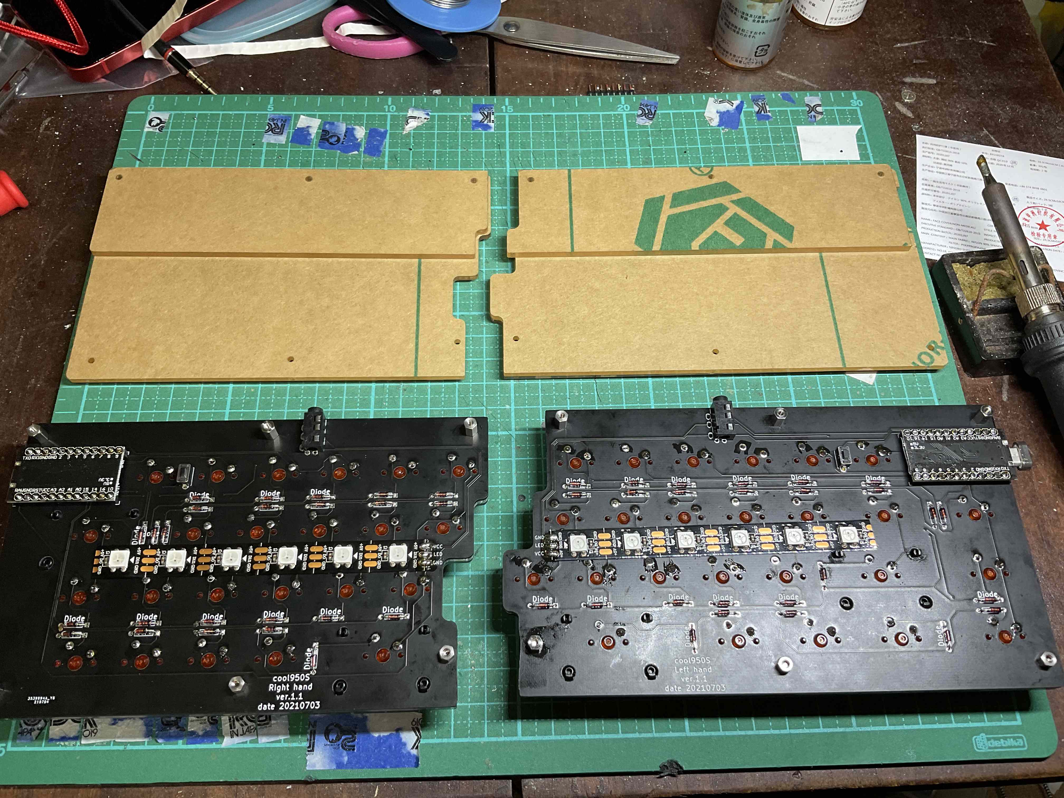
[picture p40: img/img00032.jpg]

ハンダ付けではフラックスを多めに塗布して、
ハンダをたっぷりと流し込んで、ブリッジさせます。<br>
ブリッジが上手にできない時、ダイオードの切り離した足を、必要な長さに切ります。<br>
切り離した足を、PCBの端子とLEDテープの端子とがつながるような位置でハンダ付けをします。この方法で繋ぐことができます。<br>
光らせることに興味がない場合は、装着しなくてもキーボードとしての機能に問題はありません。
しかし、光らないよりは光るほうが、キーボードは格好良く見えます。LEDテープを装着することを推奨します。<br>
また、しばらく、LEDテープなしで使用してみて、後で光らせたくなっても大丈夫です。<br>
LED装着して光らせた様子<br>
https://twitter.com/0002ozlet/status/1418925920866299905

##　１１　pro microの装着
cool950Sではマック８コンスルー（スプリングピンヘッダ）を使用してのpro microを装着します。<br>
マック８コンスルー（スプリングピンヘッダ）の向きに気をつけて使用してください。
pro microに装着している面が下に向くように（PCBに向くように）してください。
pro microは左右それぞれに付けます。<br>
pro microは、パーツが付いている面がPCBに向くように装着します。<br>
ハンダ付けが難しい部分があります。
フラックスを多めに塗布して、ハンダを流すように取り付けると上手くいきます。<br>

## １２　導通テスト
ここで一度、動作確認をすることをお勧めます。<br>
pro microにファームウェアを入れて、仮にキーキャップを差し込んで、
キースイッチを打鍵した時に反応するかどうか、確認してください。
打鍵したけど、入力されない時は、ダイオードの向きが間違っていないか、
キースイッチ等のハンダ付けの不備が原因になります。テスターで導通を確認してください。
入力確認には、次のサイトがお勧めです。<br>
https://keyboardchecker.com 

## １３　ミドルプレート１・２、ボトムプレートの装着
PCBの下側に、ミドルプレート１・２、ボトムプレートを装着します。<br>
最初にミドルプレート１（隙間の多いアクリルプレートです）を重ねます。<br>
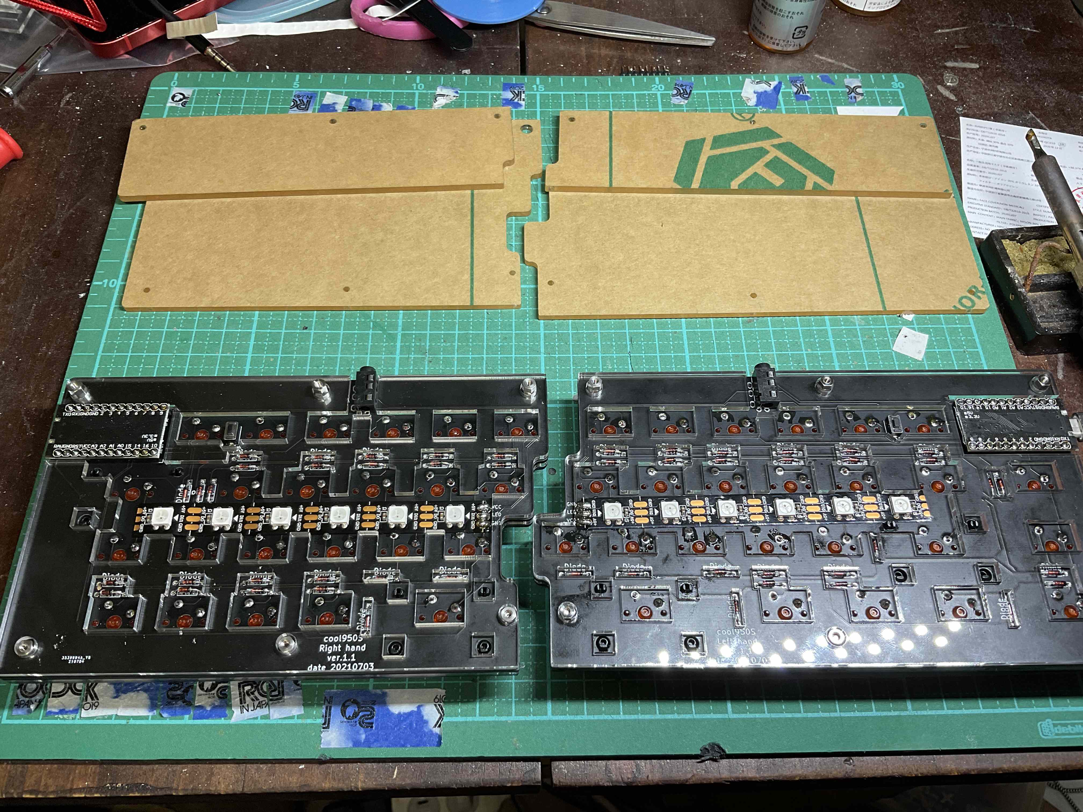
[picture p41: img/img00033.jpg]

特に右手側のミドルプレート１（上の画像だと、左側にあります）は形状的にpro micro付近が破損しやすいので、注意して取り扱ってください。<br>
次にミドルプレート２を重ねます。
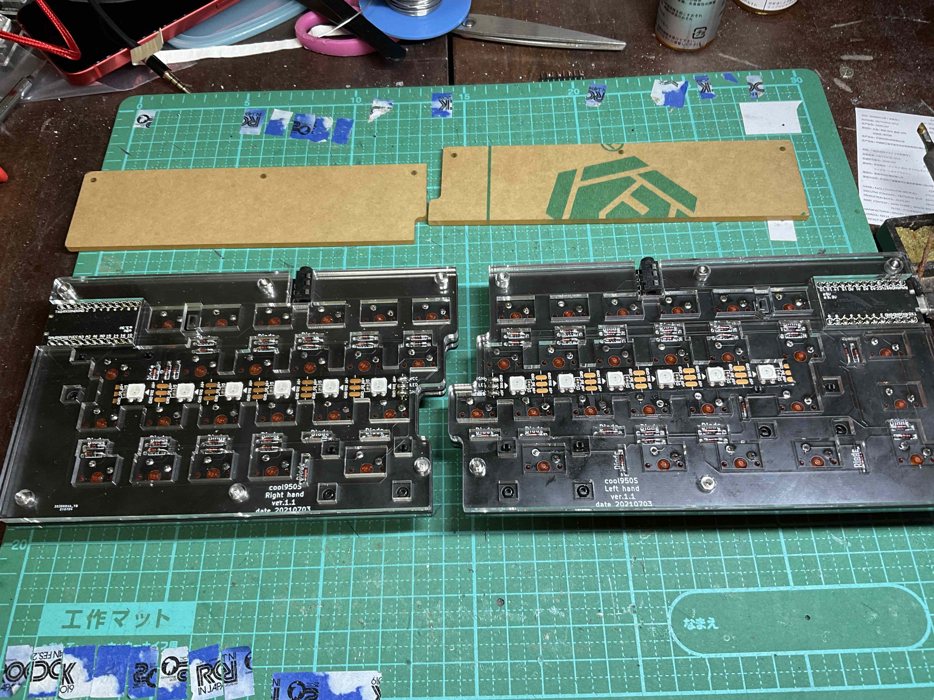
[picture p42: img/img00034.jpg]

重ねたら、左右それぞれ手前側の合計６箇所に、ねじ止めをします。<br>
M2ネジ3mmで固定してください。
最後にボトムプレートを重ねます。<br>
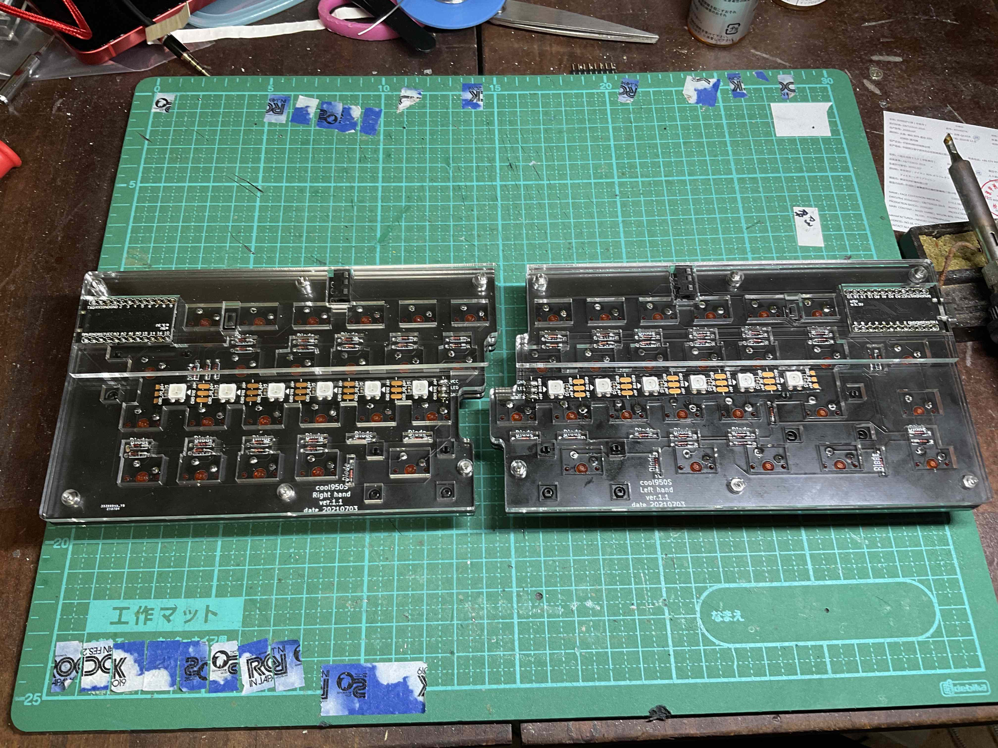
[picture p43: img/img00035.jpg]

重ねたら、左右それぞれ奥側の合計６箇所に、ねじ止めをします。<br>
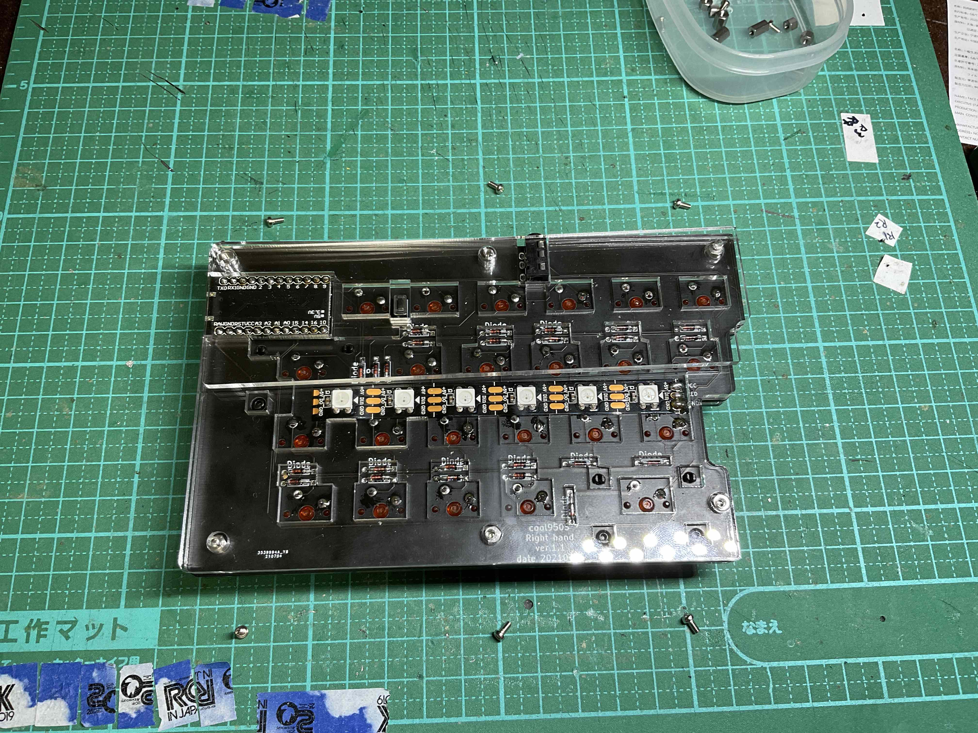
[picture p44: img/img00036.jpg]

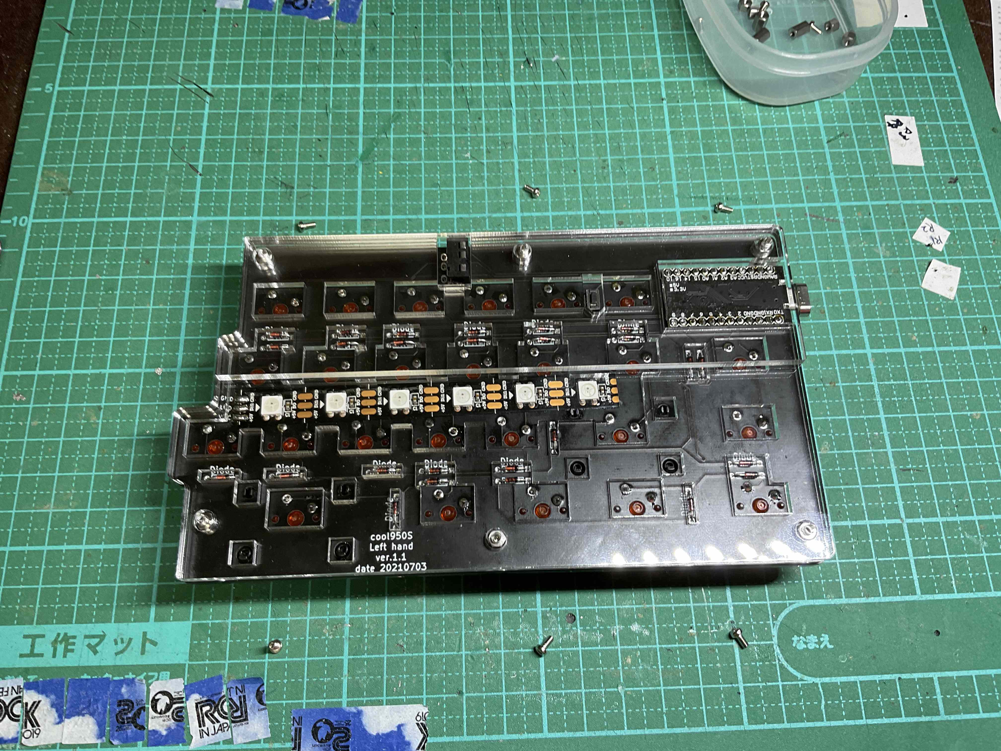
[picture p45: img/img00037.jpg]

M2ネジ3mmで固定してください。<br>
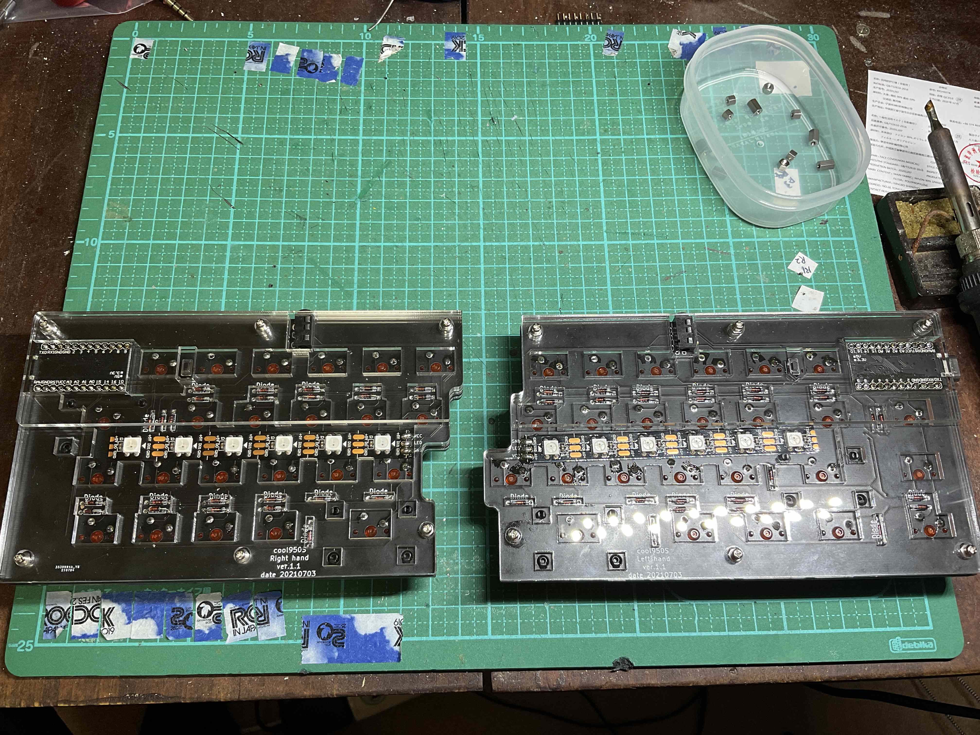
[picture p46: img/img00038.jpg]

ここで、奥側のM2スペーサー6mmではなく、5mmを使っている場合、ネジが上手くしまらないことがあります。
その時は、トッププレート側のネジを少し緩めると、ボトムプレート側のネジがしまります。
その後、トップレート側のネジをしめてください。<br>

## １４　ゴム足の装着（任意）
別途購入したゴム足を左右それぞれに取り付けてください。<br>
取り付け場所については、下の画像を参考にしてください。<br>
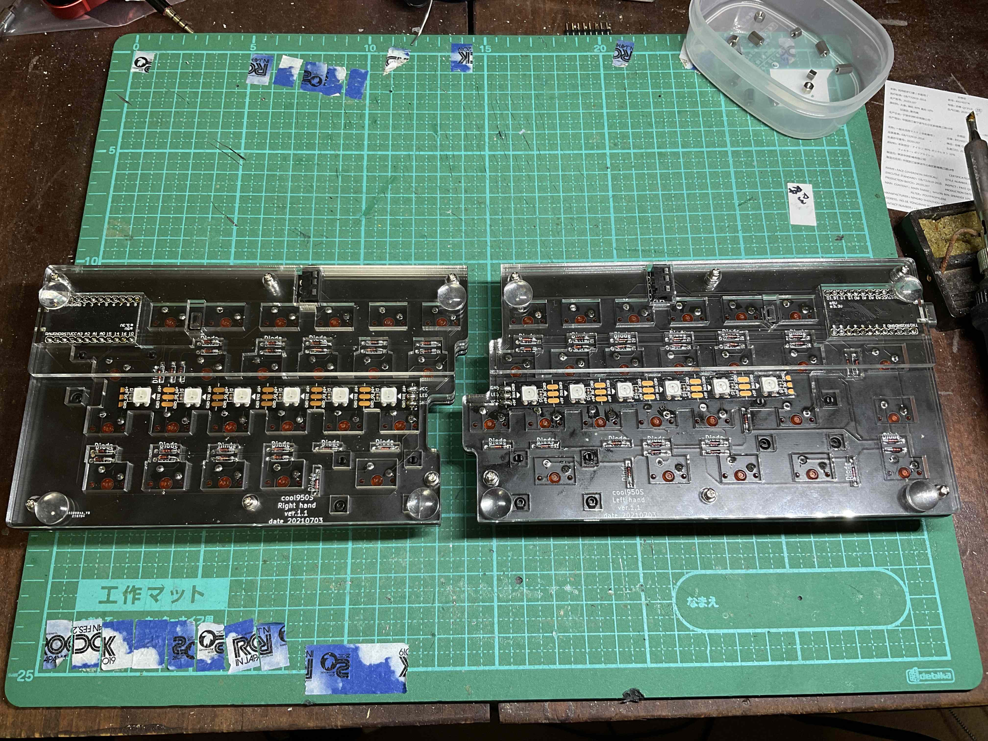
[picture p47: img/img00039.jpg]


## １５　キーキャップの装着
お気に入りのキーキャップを入手して、装着してください。<br>

cool950Sの特徴の一つは、キーキャップの選択の幅が広いことです。
キーキャップのベースキットであれば、そこに含まれているキーキャップのみで、cool950Sに装着できます。
一部だけ、別のキーキャップを装着することなく、対応できます。<br>
これで完成です。<br>


自分だけのcool950Sができましたか。<br>

打鍵テストの様子<br>
https://twitter.com/0002ozlet/status/1418936223045865472

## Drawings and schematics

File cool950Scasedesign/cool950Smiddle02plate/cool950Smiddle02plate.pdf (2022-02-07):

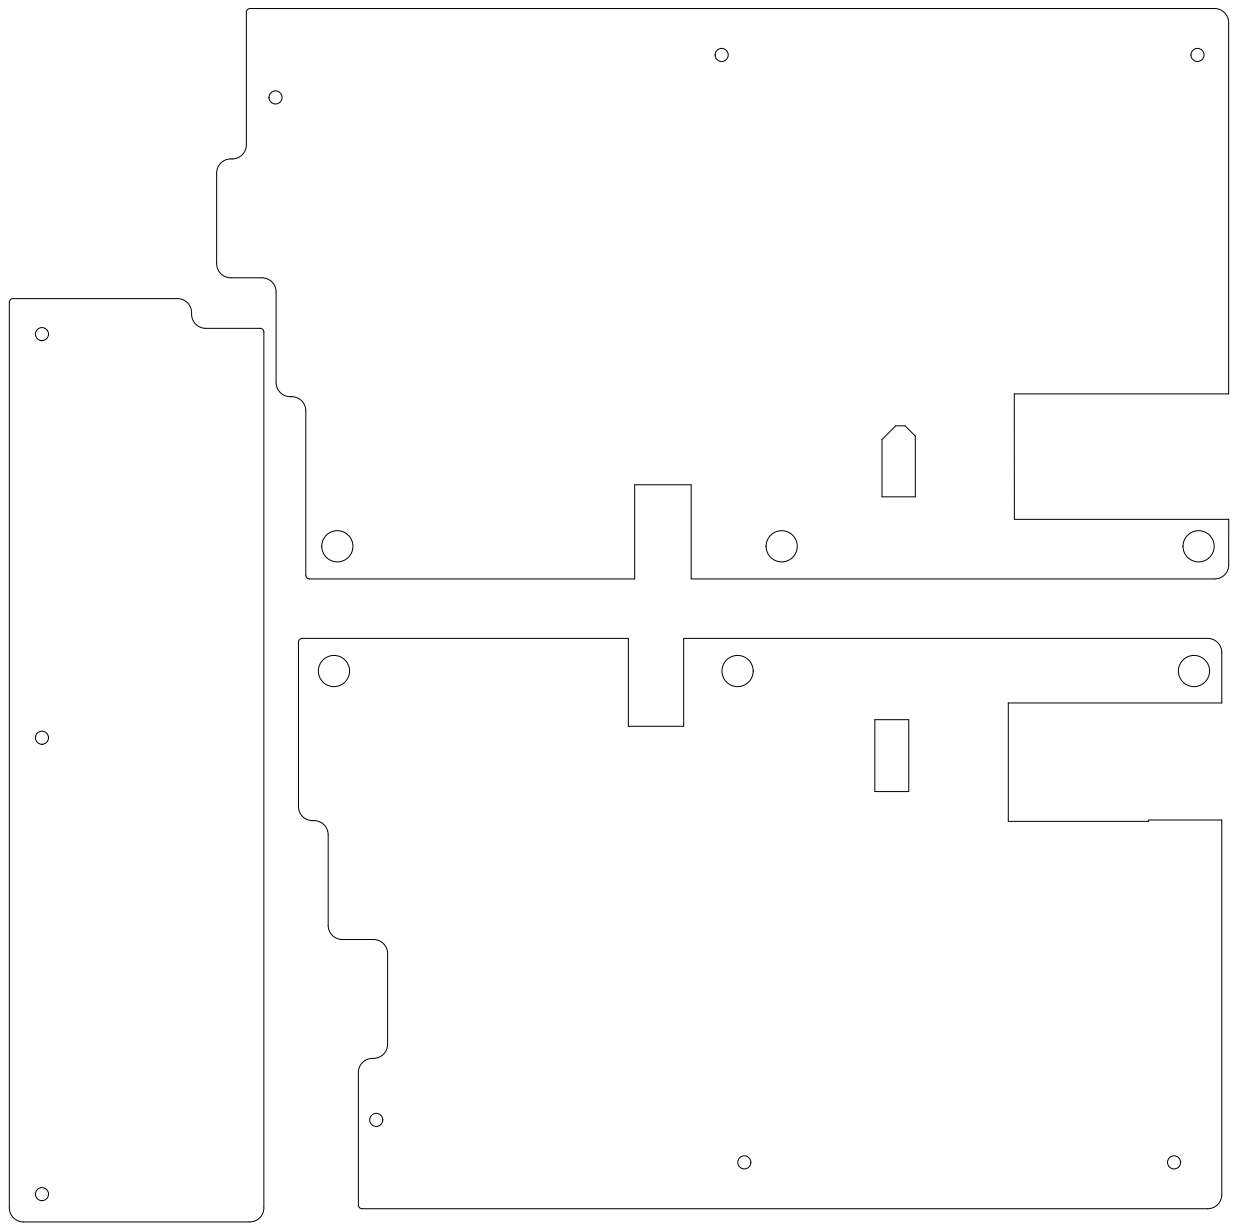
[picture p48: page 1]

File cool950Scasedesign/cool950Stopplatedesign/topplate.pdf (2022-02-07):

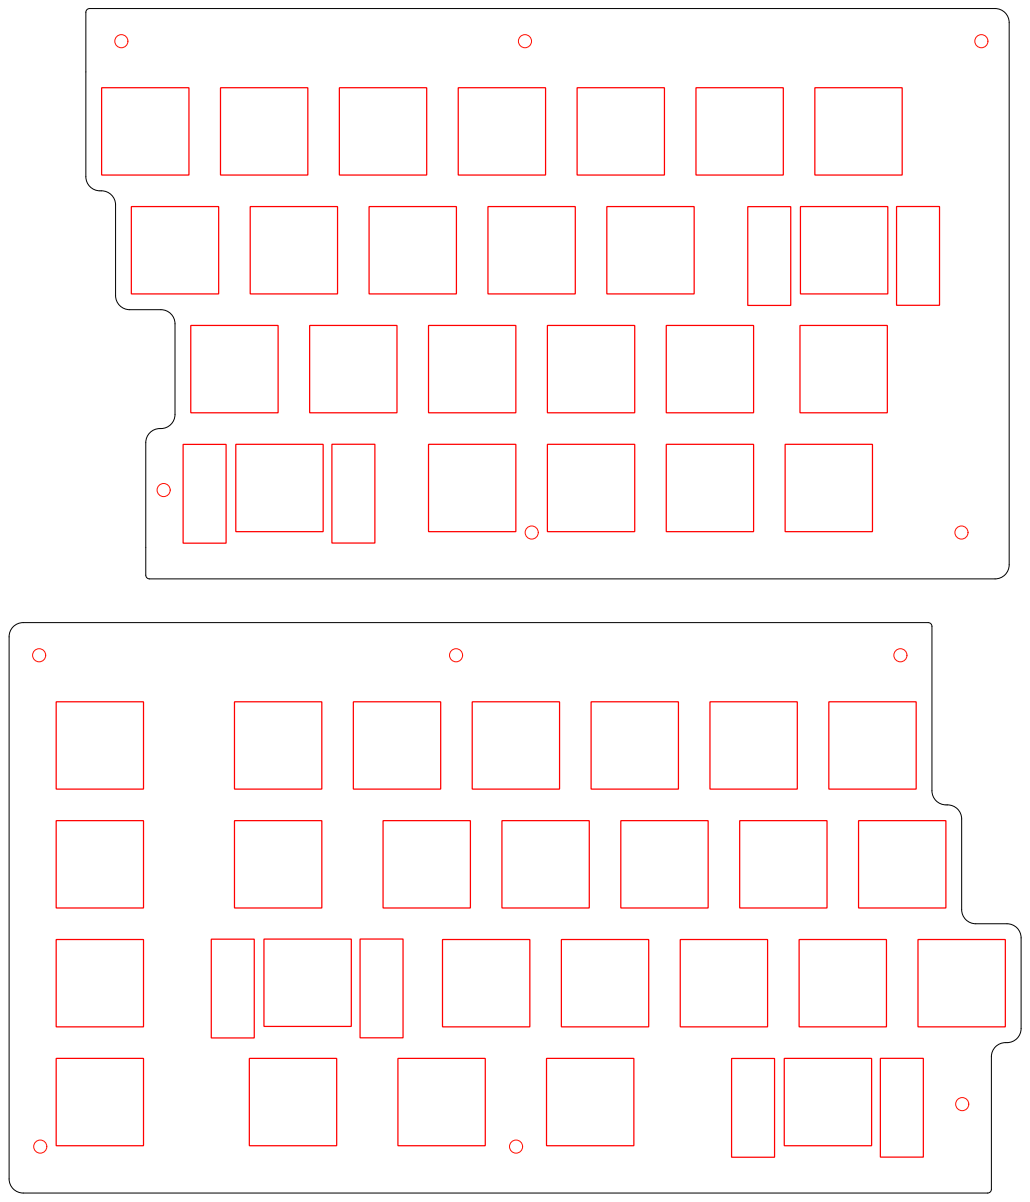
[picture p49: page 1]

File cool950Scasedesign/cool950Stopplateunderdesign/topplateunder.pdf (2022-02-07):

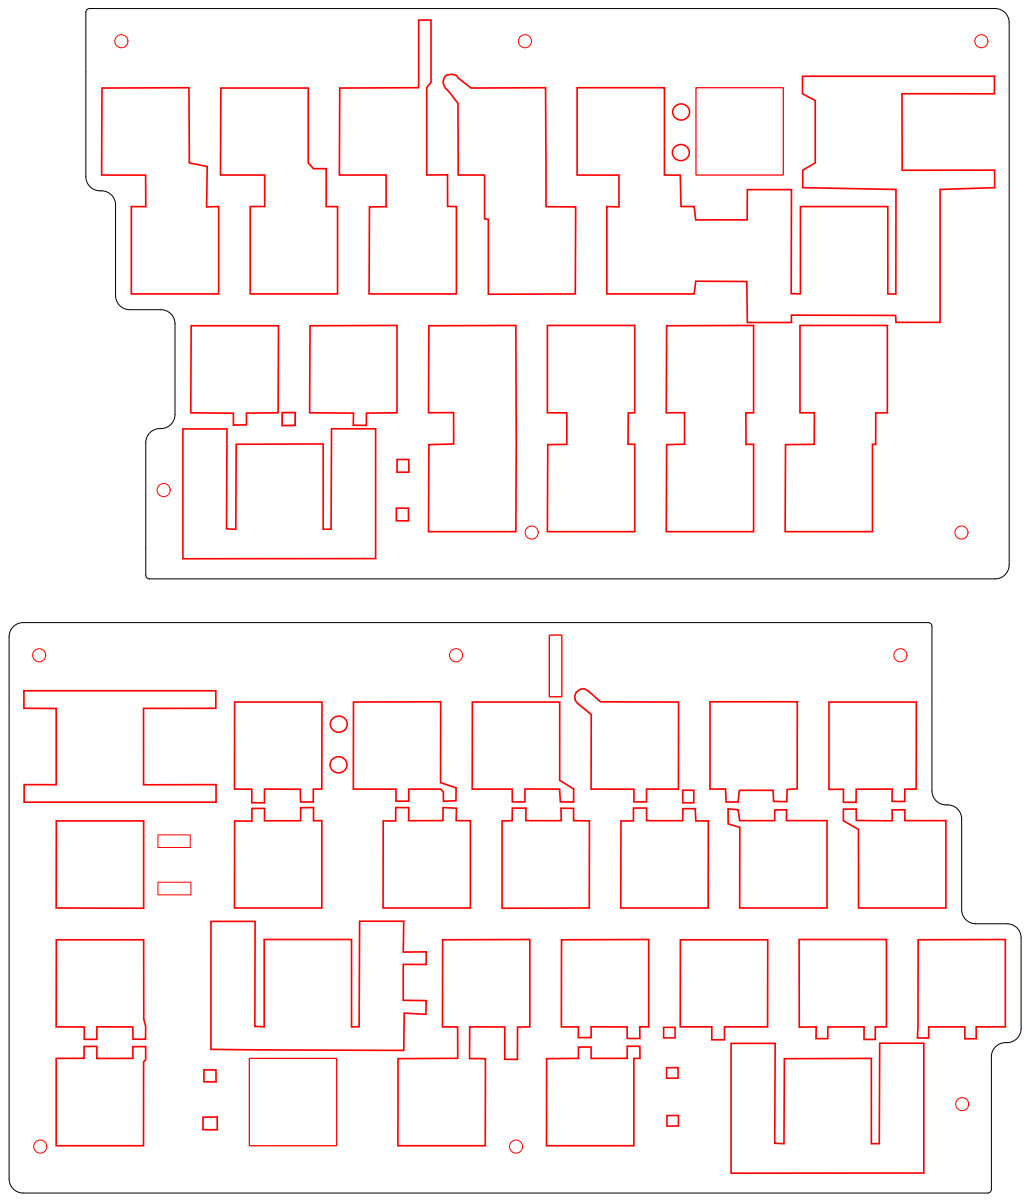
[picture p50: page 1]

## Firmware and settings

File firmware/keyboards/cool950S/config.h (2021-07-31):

/*
Copyright 2021 m.ki

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
You should have received a copy of the GNU General Public License
along with this program.  If not, see <http://www.gnu.org/licenses/>.
*/

#pragma once

#include "config_common.h"

/* USB Device descriptor parameter */
#define VENDOR_ID    0xFEED
#define PRODUCT_ID   0x0000
#define DEVICE_VER   0x0001
#define MANUFACTURER m.ki
#define PRODUCT      cool950S
#define DESCRIPTION     Split 50 percent staggered keyboard

/* key matrix size */
#define MATRIX_ROWS 8
#define MATRIX_COLS 7

/*
 * Keyboard Matrix Assignments
 *
 * Change this to how you wired your keyboard
 * COLS: AVR pins used for columns, left to right
 * ROWS: AVR pins used for rows, top to bottom
 * DIODE_DIRECTION: COL2ROW = COL = Anode (+), ROW = Cathode (-, marked on diode)
 *                  ROW2COL = ROW = Anode (+), COL = Cathode (-, marked on diode)
 *
 */
#define MATRIX_ROW_PINS { F6, F7, B1, B3 }
#define MATRIX_COL_PINS { D1, D0, D4, B5, D7, E6, B4 }
#define UNUSED_PINS

/* COL2ROW, ROW2COL */
#define DIODE_DIRECTION ROW2COL

/*
 * Split Keyboard specific options, make sure you have 'SPLIT_KEYBOARD = yes' in your rules.mk, and define SOFT_SERIAL_PIN.
 */
#define SOFT_SERIAL_PIN   D2  // or D1, D2, D3, E6
#define RGBLIGHT_SPLIT
#define RGBLED_SPLIT { 6, 6 }

//#define LED_NUM_LOCK_PIN B0
//#define LED_CAPS_LOCK_PIN B1
//#define LED_SCROLL_LOCK_PIN B2
//#define LED_COMPOSE_PIN B3
//#define LED_KANA_PIN B4

//#define BACKLIGHT_PIN B7
//#define BACKLIGHT_LEVELS 3
//#define BACKLIGHT_BREATHING

#define RGB_DI_PIN D3
#    define RGBLED_NUM 16
#    define RGBLIGHT_HUE_STEP 8
#    define RGBLIGHT_SAT_STEP 8
#    define RGBLIGHT_VAL_STEP 8
#    define RGBLIGHT_LIMIT_VAL 255 /* The maximum brightness level */
#    define RGBLIGHT_SLEEP  /* If defined, the RGB lighting will be switched off when the host goes to sleep */
/*== all animations enable ==*/
#    define RGBLIGHT_ANIMATIONS
/*== or choose animations ==*/
#    define RGBLIGHT_EFFECT_BREATHING
#    define RGBLIGHT_EFFECT_RAINBOW_MOOD
#    define RGBLIGHT_EFFECT_RAINBOW_SWIRL
#    define RGBLIGHT_EFFECT_SNAKE
#    define RGBLIGHT_EFFECT_KNIGHT
#    define RGBLIGHT_EFFECT_CHRISTMAS
#    define RGBLIGHT_EFFECT_STATIC_GRADIENT
#    define RGBLIGHT_EFFECT_RGB_TEST
#    define RGBLIGHT_EFFECT_ALTERNATING
/*== customize breathing effect ==*/
/*==== (DEFAULT) use fixed table instead of exp() and sin() ====*/
#    define RGBLIGHT_BREATHE_TABLE_SIZE 256      // 256(default) or 128 or 64
/*==== use exp() and sin() ====*/
#    define RGBLIGHT_EFFECT_BREATHE_CENTER 1.85  // 1 to 2.7
#    define RGBLIGHT_EFFECT_BREATHE_MAX    255   // 0 to 255
//#endif

/* Debounce reduces chatter (unintended double-presses) - set 0 if debouncing is not needed */
#define DEBOUNCE 5

/* define if matrix has ghost (lacks anti-ghosting diodes) */
//#define MATRIX_HAS_GHOST

/* Mechanical locking support. Use KC_LCAP, KC_LNUM or KC_LSCR instead in keymap */
#define LOCKING_SUPPORT_ENABLE
/* Locking resynchronize hack */
#define LOCKING_RESYNC_ENABLE

/* If defined, GRAVE_ESC will always act as ESC when CTRL is held.
 * This is useful for the Windows task manager shortcut (ctrl+shift+esc).
 */
//#define GRAVE_ESC_CTRL_OVERRIDE

/*
 * Force NKRO
 *
 * Force NKRO (nKey Rollover) to be enabled by default, regardless of the saved
 * state in the bootmagic EEPROM settings. (Note that NKRO must be enabled in the
 * makefile for this to work.)
 *
 * If forced on, NKRO can be disabled via magic key (default = LShift+RShift+N)
 * until the next keyboard reset.
 *
 * NKRO may prevent your keystrokes from being detected in the BIOS, but it is
 * fully operational during normal computer usage.
 *
 * For a less heavy-handed approach, enable NKRO via magic key (LShift+RShift+N)
 * or via bootmagic (hold SPACE+N while plugging in the keyboard). Once set by
 * bootmagic, NKRO mode will always be enabled until it is toggled again during a
 * power-up.
 *
 */
//#define FORCE_NKRO

/*
 * Feature disable options
 *  These options are also useful to firmware size reduction.
 */

/* disable debug print */
//#define NO_DEBUG

/* disable print */
//#define NO_PRINT

/* disable action features */
//#define NO_ACTION_LAYER
//#define NO_ACTION_TAPPING
//#define NO_ACTION_ONESHOT

/* disable these deprecated features by default */
#define NO_ACTION_MACRO
#define NO_ACTION_FUNCTION

/* Bootmagic Lite key configuration */
//#define BOOTMAGIC_LITE_ROW 0
//#define BOOTMAGIC_LITE_COLUMN 0

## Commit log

2021-07-30 画像追加等
2021-07-30 ツイート埋め込み修正
2021-07-31 画像追加
2021-07-31 画像追加修正
2021-07-31 文字修正
2021-08-02 記述の誤りを修正

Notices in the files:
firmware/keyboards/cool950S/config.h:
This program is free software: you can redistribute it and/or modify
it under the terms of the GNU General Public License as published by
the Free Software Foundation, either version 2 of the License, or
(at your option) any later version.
